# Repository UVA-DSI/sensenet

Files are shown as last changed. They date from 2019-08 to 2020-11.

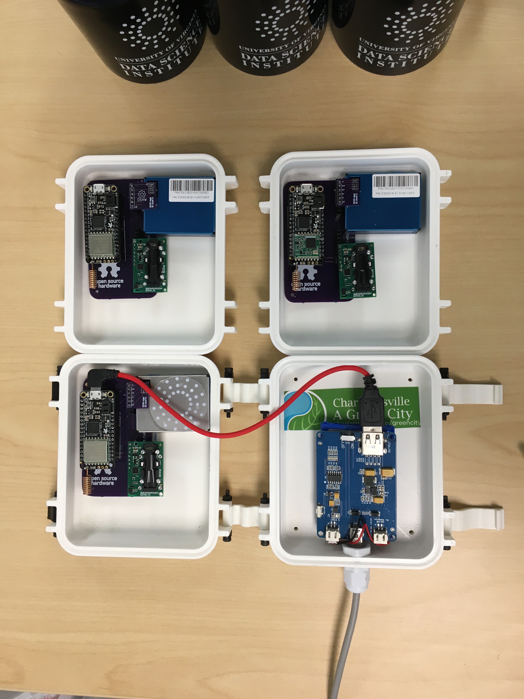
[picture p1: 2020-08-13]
projects/CCI-SDS/images/scville-hw-kit-assembled3.jpg

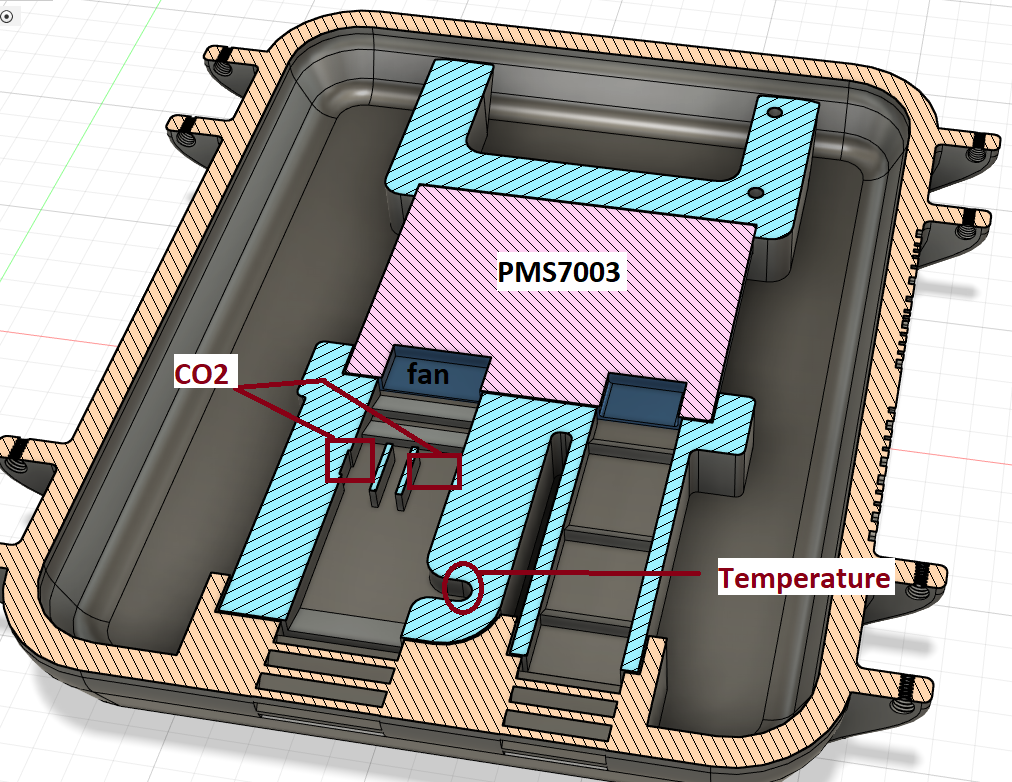
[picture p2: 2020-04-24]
projects/CCI-SDS/3D-design/box/Sensenet_Internal_cut2.png

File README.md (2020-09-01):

# Sensenet: networked environmental sensing for all

This repository contains the documentation for the 'Sensenet'
project. Here you will find the software and hardware sources 
for the backend, frontend, and sensor devices we use.

## What is included in this repository

We organized projects in folders with their resources (hardware, 
firmware, software, datasheets, and relevant documentation).

We also included 'playbooks' for the backend configuration under the
directory 'ansible' and 'conf'. They are meant to provision the 
complete backend which includes: [MQTT broker (mosquitto)](mqtt.md), 
timeseries database (influx-db), and a visualization tool (Grafana). 
For more info about the line protocol used for the timeseries db, 
[check our documentation](timeseries-db.md).

Each directory contains information about the sensors we are testing.
For more details, [check out the 'sensor-specification'](sensor-spec.md) 
document and the 'datasheets' directory.

## Implementations

We use different sensors, microcontrollers, and tools for different
implementations. You can get more information about each set-up following
the links below:

* [Networked Public Spaces, 2020-2021](projects/NPS/README.md)
* [Smartcville + School of Data Science, 2019-2020](projects/CCI-SDS/README.md)

## Contact and licensing info

Check the AUTHORS file for the list of contributors. For more 
information about each project, check the file CONTRIBUTORS.

All software is licensed as GPLv3; all hardware is licensed as
CERN-OHL-S-v2, and all documentation is released as 'CC-BY-SA-4.0
International', unless specified in the LICENSE file included in
the directory or in the header of source files.

__Happy environmental sensing and hw hacking!__

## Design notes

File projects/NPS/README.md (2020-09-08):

# Networked Public Spaces (NPS) project

"Network Public Spaces" is a collaborative project involving the School
of Data Science and the School of Architecture at UVA for the study and
implementation of community-based environmental sensor networks.

In this repository you will find the design files and source code for the
development board we are designing for low-energy LoRa applications.

## Development board 

Under the folder ["board"](board/) we keep all the design files under 
development for our dev board, sensenet: Big Dot.

## Testing 

We are using the SAML21 Xplained board for testing purposes. The information
on how to flash the bootloader we use on this board can be found at 
[SAML21-XPLAINED folder](SAML21-xplained-board/README.md).

## Installations

Ostenda Illuminata is the first installation of this project. Source code
can be found in the folder `ostenda-esp32s`.

## Dev team

Our team is composed by:

-
-
- 

Alumni:

- Keerthi Radhakrishnan

## Contact and licensing info

Please check the AUTHORS and LICENSE files for more info.

__Happy hardware hacking!__

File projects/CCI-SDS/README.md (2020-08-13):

# A LoRaWAN-Based Air Quality Sensor Network for the Public Good (2019-2020)

In this project, we evaluated, tested, and deployed a pilot wireless sensor network in collaboration 
with the Center for Civic Innovation, Smart Cville, and the UVA Linklab. This project was conducted 
by James Howerton and Ben Schenck under the mentorship of L.F.R. Murillo, Jon Kropko, Lucas Ames, and 
Jon Goodall.

Here you will find the technical document for the hardware, firware, and software we developed and used
for this project. This README is for development purposes only. 

For more information, [please visit the portfolio and access the paper "A LoRaWAN-based AQ Sensor 
Network for the Public Good" by Howerton and Schenck](https://thejimster82.github.io/CvilleAQ).

## Things Network Cville

Our project took advantage of an existing LoRa network in the city of Charlottesville. This network is 
run by Smart Cville as an open community resource. When we started, there were only 5 gateways. We expanded
the network, so it now counts with [12 gateways that can seen here](https://www.thethingsnetwork.org/community/charlottesville/).

## Data

We collected PM2.5 (ppm), PM10 (ppm), temperature (C), CO2 (ppm) and humidity (%) with 10 boxes for 
the period of five months. This data can be obtained directly from our visualization tool below, or [already 
cleaned and ready to use in this directory](https://github.com/thejimster82/CvilleAQ/tree/master/notebooks/data).

For information on how to query for data on Influxdb, please use this [notebook](https://github.com/UVA-DSI/sensenet/blob/master/projects/CCI-SDS/notebooks/influxdb-sensenet-example.ipynb). Our data is made "open" according to the ["Open Data" definition](http://opendatahandbook.org/guide/en/what-is-open-data/).

## Data Visualization

We are using two platforms to visualize the data we generated: Grafana and Luftdaten. The first
includes the unprocessed data from our ground sensors. The latter is a global network for particulate
matter sensing (PM). We use their mapping tool to visualize our data and to calculate the official
index of the US Environmental Protection Agency (EPA "Air Quality Index").

[Click here to visualize in real-time our environmental metrics (of the last 24 hours.](https://sensors.unixjazz.org/d/xUrC1m8Zz/sbox-all?from=1583213342024&to=1583299742024&orgId=1)

You can pick different time periods or select individual sensors by clicking on them, next to the graph.
Our data collection period started in February, 2020 and ended in June, 2020.

[Click here to visualize how these values map out to city locations.](https://maps.sensor.community/#13/38.0307/-78.4931)

You can select different metrics, such as (PM2.5, PM10 or check the EPA AIQ calculation) by clicking on 
the green menu at the bottom left of the map. Several zoom levels can also be selected, but the zoom
stops at #15 to avoid providing close GPS coordinates for where the environmental sensor is actually 
located.

## Hardware

We have deployed a sensor box equipped with the following hardware:

* SAMD21 microcontroller 
* LoRa RFM98 radio chip
* PMS7003 particulate matter sensor
* Sensiron SCD30 CO2 sensor
* Voltaic 1W solar panel + 4000mAh battery

The firmware can be found in the 'sensorbox' folder. The 'hardware' folder contains the connectors
and 'motherboard' PCBs we generated for this project. Here is picture of [our first prototype, v.1](images/proto_v1.jpg),
and here is another of our revised prototype [v.2](images/proto_v2.jpg). We also included more pictures  
of the hardware in the folder "images".

### How to Use the Sensor Box

The sensor boxes have been insulated with silicone coating and protected with a watertight box. It is
not, however, completely insulated as it contains holes for the sensors. Here are the elements one must
pay attention to:

* Placement: the boxes are placed at ground level (up to 10 meters), exposed to sun light, but
protected from direct rain and snow. Once it is placed in one location, write down the coordinates,
and do not move it.

* Wiring: here are the schematics on [how to wire the sensors to the microcontroller board.](images/wiring.png)

* Battery: our set-up is currently not adjusted for low-power applications, it will not last on a battery 
for more than a week if there is no sun exposure. In our experience, the 4000mAh will last for 12 days on average
without sun exposure. During the summer, however, the box does not need to be recharged if properly placed in a 
sunny spot. [Here are the instructions to put the battery on "Always On mode, which is ** necessary ** 
for its functioning in our set-up.](https://voltaicsystems.com/always-on-batteries)

## Firmware

All the code is located in the folder "sensorbox" under the name of "sbox0".

## Data Analysis

The end goal is to use the data we collected for evaluating the health impact of compounded environmental
metrics. There are three basic directions: 1) calculating averages and displaying their geolocation; 2)
creating a geospatial model for evaluating how certain concentrations might affect different parts of 
the city and certain vulnerable groups; and 3) experiment with ML-based models for outlier detection
and sensor calibration.

For more information about data analytics, check the Jupyter notebooks we prepared under the folder "notebooks".

## Commitment to Data Ethics, Privacy & Security

One of the key goals was to introduce data science students to "open data" practices (open standards, APIs,
data practices w/ Free and Open Source software and hardware) while helping them navigate data ethics issues 
to dispel the idea that public data is exempt of ethical implications.

Questions of concern for the project participants are: What are the ethical implications of 
large-scale data collection for individuals and public institutions? How should open data be gathered, 
distributed, and used? How should sensor data be collected, organized, and distributed, taking into account 
individual rights to anonymity and privacy? What qualifies as consent in our network and what are the limits
of data capture? And, finally, why we do not need an "Internet of Things" but an "Internet of People"? That is,
a network that is owned and managed by the public for the public good?

Our dataset does not include data from humans, but that does not mean it does not have ethical implications. 
Exact GPS coordinates for the location of our boxes were not made publically avaliable, only approximate sensor locations
are being published. Our commitment to openess with respect to our technologies and infrastructures does not mean
we do not value privacy rights and indiscriminate data collection. Our primary goal is to collect environmental data
whose benefit includes every breathing and living being. For our purposes, we believe it is justifiable and justified
to collect environmental data to address environmental issues and questions of environmental justice.

## Contact and Licensing Info

Check the file AUTHORS for the list of contributors to this repository. For licensing information, check the
header of a source file or the file LICENSE in the directory of a particular resource (firmware, software,
research notebook, etc.).

__Happy Environmental Monitoring and Hardware Hacking!__

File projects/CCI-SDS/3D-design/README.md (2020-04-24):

# 3D Design Files

We included here the 3D design files for the Smart Cville + School of Data Science project.
Here you will find:

* Support structures for sensors ('suport/')
* Insulated sensor box ('box/')
* Other support files

## Authors and Licensing info

3D box design was done by Luke Pi (@zx82net, Thingiverse), 2019 and Leonardo R. Murillo, 2020.
3D sensor support design was done by Leonardo R. Murillo, 2020.

All design files are distributed with CC-BY-NC-SA 4.0 International.

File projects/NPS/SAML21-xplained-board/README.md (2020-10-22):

# SAML21 Prototyping Notes

In this document, we describe the steps for setting up the SAML21 Xplained Pro dev board.

## Bootloader Installation

We must use a set of tools for writing the bootloader and firmware files to the SAML21 for prototyping purposes. Here are the steps to get it up and running:

**Dependencies**

- OpenOCD v.0.10.0 or superior
- [GCC-arm-none-eabi-7-2017-q4-major](https://developer.arm.com/tools-and-software/open-source-software/developer-tools/gnu-toolchain/gnu-rm/downloads) (this is also included in the official fork of ArduinoCore-SAMD, installable through the Arduino IDE Boards Manager)
- [BOSSA](https://github.com/shumatech/BOSSA/releases)
- Debian 10 (or any other distro) w/ extra packages: 'libwxgtk3.0-dev' and 'libreadline-dev'
- [Mattair's fork of ArduinoCore w/ SAML21 support](https://github.com/mattairtech/ArduinoCore-samd) (install instructions are towards the bottom of the README.md of that repository)

### Building the Bootloader

*Note: there are precompiled binaries included in the `bootloader` directory*

We need to build the bootloader for our board and our specific target MCU. Change to the directory `bootloader/ArduinoCore-samd-1.6.18-beta-b1/bootloaders/zero` and type:

```
$ BOARD_ID=XPLAINED_SAML21 MCU=SAML21J18B make all mostly_clean
```

After a few moments, you will have the bootloader (8K) with USB terminal support ready in the file `sam_ba_XPLAINED_SAML21_SAML21J18B.bin`.

### Runing OpenOCD

#### Using Atmel EDBG

Plug the USB cable on the 'debug USB' port and run OpenOCD w/ the configuration file included in the `openocd-conf` directory.

```
$ openocd -f openocd-SAML21.cfg
```
If everything goes as planned, you will see this output:

```
cortex_m reset_config sysresetreq
Info : CMSIS-DAP: SWD  Supported
Info : CMSIS-DAP: Interface Initialised (SWD)
Info : CMSIS-DAP: FW Version = 03.25.01B6
Info : SWCLK/TCK = 1 SWDIO/TMS = 1 TDI = 1 TDO = 1 nTRST = 0 nRESET = 1
Info : CMSIS-DAP: Interface ready
Info : clock speed 400 kHz
Info : SWD DPIDR 0x0bc11477
Info : at91saml21j18.cpu: hardware has 4 breakpoints, 2 watchpoints
```

Do not close this terminal or exit out of OpenOCD for the next steps. 

#### Using ATMEL-ICE

If you are privileged enough to have an ATMEL ICE programmer, you can use it to program the bootloader on a brand new chip. 

Please note that you can also use any STM32F103 that you might have laying around... 
In any case, here is how to do it with the super expensive programmer!

First, ensure the 'target chip' is set properly to match your chip in the `openocd-ATMEL-ICE.cfg` file.

```T
# target chip
set CHIPNAME at91saml21j18
source [find target/at91samdXX.cfg]
```

 Plug your programmer's SAM port to the "Cortex Debug" header of your board. Then, power your board via the target USB port with and run:

```
$ openocd -f openocd-ATMEL-ICE.cfg
```

This is the output you will see on your console:

```
Info : Listening on port 6666 for tcl connections
Info : Listening on port 4444 for telnet connections
Info : CMSIS-DAP: SWD  Supported
Info : CMSIS-DAP: JTAG Supported
Info : CMSIS-DAP: FW Version = 01.00.0021
Info : CMSIS-DAP: Serial# = J42700024764
Info : CMSIS-DAP: Interface Initialised (SWD)
Info : SWCLK/TCK = 1 SWDIO/TMS = 1 TDI = 1 TDO = 1 nTRST = 0 nRESET = 1
Info : CMSIS-DAP: Interface ready
Info : clock speed 400 kHz
Info : SWD DPIDR 0x0bc11477
Info : at91saml21j18.cpu: hardware has 4 breakpoints, 2 watchpoints
Info : starting gdb server for at91saml21j18.cpu on 3333
Info : Listening on port 3333 for gdb connections
```

Do not close this terminal or exit out of OpenOCD for the next steps.

### Write Bootloader

If you are dealing with a new chip, you will have to write the bootloader and set the fuses to protect it w/ OpenOCD. First connect to the chip:

```
$ telnet 0 4444 
```
Now you can write the bootloader:

```
reset halt
at91samd bootloader 0
program sam_ba_Generic_x21J_SAML21J18B.bin verify
at91samd bootloader 8192	# this command is optional, recommended to prevent BOSSA from erasing bootloader
reset
shutdown
```
The precompiled bootloader image for the SAML21J18B was obtained from the Mattair's repository. You can find more information on how to compile the bootloader image from the documentation of his fork.

If everything goes well, you are now ready to write your programs using the Arduino core framework to the target (SAML21). This is the output of a successful verification:

```
** Programming Started **
auto erase enabled
Info : SAMD MCU: SAML21J18B (256KB Flash, 32KB RAM)
wrote 16384 bytes from file /home/unixjazz/code/SAML21-xplained-board/bootloader-arduino/sam_ba_Generic_x21J_SAML21J18B.bin in 3.540651s (4.519 KiB/s)
** Programming Finished **
** Verify Started **
verified 4964 bytes in 0.181510s (26.707 KiB/s)
** Verified OK **
** Resetting Target **
```

You should verify if everything is fine by checking if the board is properly enumerated by running

```
# dmesg
```

This should return the following output:

```
usb 3-1.2: New USB device found, idVendor=0000, idProduct=0000, bcdDevice= 2.00
usb 3-1.2: New USB device strings: Mfr=1, Product=2, SerialNumber=0
cdc_acm 3-1.2:1.0: ttyACM0: USB ACM device
```

Please note that for actual usage, a board definition needs to be specified with the SAML21 Xplained board pinout. We currently do not have the board description ready for Big Dot. This is on our the TODO list.

Voilà! Toolchain and programmer are now ready for embedded fun to start.

### Flash Your Firmware

You are now ready to upload an Arduino sketch (such as `usb-term-test.bin` under the `sketches` directory) to test the USB terminal.

If you plug your board using the 'target USB' port, it should enumerate and you should have access to it. Now, you can use any tool to program your device using the USB port. You can use any sketch that makes use of USB output to test.

## Using BOSSA

Once you have the bootloader installed, you can use the `bossa` GUI utility or the `bossac` command-line utility to flash firmware onto the chip.

### Compile BOSSA

Just run `make` and `make install` to get it all ready. The binaries will be on the folder 'bin/' (`bossa`: GUI, and `bossac`: command-line tool).

### Flashing the Sample Firmware

First, test that the bootloader is successfully installed by attempting to flash the demo firmware:

```
$ bossac -e -w -v -o 8192 -b usb-term-test.bin
```

If it is successful, then you should get the following message:

```
Erase flash

Done in 0.901 seconds
Write 11856 bytes to flash (186 pages)
[==============================] 100% (186/186 pages)
Done in 0.068 seconds
Verify 11856 bytes of flash
[==============================] 100% (186/186 pages)
Verify successful
Done in 0.096 seconds
Set boot flash true
```

If you get the message

```
Device unsupported
```

and the device is properly enumerated, then press the reset button twice to enter bootloader mode.

To test to see if the sample firmware is working correctly, first open a terminal and run

```
$ screen /dev/ttyACM0
```

or use your favored serial monitor.

__Happy hw hacking!__

-- Sign-off: Teagan Le, 10/21/2020

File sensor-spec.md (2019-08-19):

# Sensor specfication

This document describes sensor names, endpoints, units,
and accuracy information. Check the 'datasheets' directory
for detailed specifications.

---
Name: BMP388
Fabricant: Bosch
Type: Temperature and pressure
```
Endpoint: 
        temp/
	press/
Units: 
        temp/		(°C celsius)
        press/ 		(hPa hectopascal)

Accuracy:  
       temp/		(±0.5 °C)
       press/   	(8 Pascals, ± 0.5 meter)
```
---
Name: SGP-30
Fabricant:
Type: 
Endpoint:
```
```

---
Sign-off: LFRM, 08-01-2019

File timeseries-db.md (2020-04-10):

# Timeseries db 'line protocol'

Influxdb is 'schemaless' which means it will generate a new series
when we send an insert statement with new 'tags' (such as sensor_type).
Once a field has been created with a particular type (float / int),
trying to write a different data type on it will generate an error.

Here is the suggested structure for data points on the database:

```
NETWORK_NAME,dev=DEV_ID,loc=DEV_LOC,topic=SENSOR_TYPE value=VALUE TIMESTAMP
```

Where:

* 'NETWORK_NAME': sensor network identifier (string)
* 'DEV_ID': device identifier (string)
* 'DEV_LOC': device localization (string)
* 'SENSOR_TYPE': temp, CO2, lux, pm25, CO2, humidity, etc. (string)
* 'VALUE': sensor measurement value (float)
* 'TIMESTAMP': timestamp of measurement (Unix epoch)

Here is an example:
```
sds-sensenet,dev=sbox1,loc=loc0,topic=temp value=32.02 1566183001355985604
```

Observations:

* There is no need to provide a TIMESTAMP (if running NTP);
* TIMESTAMP is always UTC (in Unix epoch format);
* Field keys (value) are required, they are always strings;
* Field values are 'floats' by default;
* Tags are indexed, fields are not: avoid having too many tags.

## Influxdb basic query language

For queries, we can use the API or the influxdb client:

```
influx -host example.org -port 8086 -ssl -username $USER -p YOURPASSWD
```

If self-signed certificates are being used, add '-unsafeSsl'.
You can also display timestamps in RFC-3339 format by adding '-precision rfc3339'. 
The date-time will be conveniently displayed in [Gregorian format / UTC](https://www.ietf.org/rfc/rfc3339.txt). 

## Basic command list

To list existing databases:

```
show databases
```

To select a particular database:

```
use $DATABASENAME 
```

To list existing 'measurements' (e.g. particular type of sensor):

```
show measurements
```

To query for the whole time series of a measurement:

```
select * from temp_sensor 
```

To insert a data point:

```
insert $MEASUREMENT metric_a=0.1, metric_b=1.90 
```

Field data types cannot be changed after they are entered for the
first time. To update any db entry, use the same timestamp with 
the 'insert' statement:

```
insert $MEASUREMENT metric_a=0.1, metric_b=1i ('i' stands for int) $ORIGINAL_TIMESTAMP
```

To delete data points from a particular period of time, use:

```
delete from $MEASUREMENT where time < or > or = ($TIME_IN_UNIX_EPOCH or "2020-02-01")
```

To move all the data from a 'measurement' (tables) to another DB, use:

```
select * into DB..$MEASUREMENT from DB2..$MEASUREMENT_TO_COPY_FROM group by *
```

Another convenient way of pulling data is using a IPython notebook and/or performing
a HTTP request with 'curl' to obtain a CSV file. You can request the whole time series
or select, for example, the past 2 days of data:

```
curl -H "Accept: application/csv" -G 'https://$YOURSERVER:8086/query' --insecure --data-urlencode "db=$YOUR_DB" -u "$USER:PASSWD" --data-urlencode "q=select * from \"sensenet-test\" where time >= now() - 2d" > db-dump.csv
```

For more info, check out the [query language documentation](https://docs.influxdata.com/influxdb/v1.7/query_language/database_management).

## TODO

* Improve the documentation
* Complete 'ansible' playbooks
* Test alternatives to 'Influx DB' (given its proprietary HA components)

---
Sign-off: LFRM, 02-02-2019

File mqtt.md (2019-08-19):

# Mosquitto MQTT broker

We use SSL for communicating between MCUs and servers
using MQTT, a light-weight protocol for transmitting
sensor data. 

After generating the certs for the servers with 
'Lets Encrypt', we can test the SSL communication 
with the following command:

```
mosquitto_sub -h example.org -t '#' -p 8883 --capath /etc/ssl/certs -u USER -P PASSWD
```

For posting on a topic, use the follwing command for testing purposes:

```
mosquitto_pub -h example.org -t test -m "hello world" -p 8883 --capath /etc/ssl/certs -u USER -P PASSWD
```

The following lines must be passwd to 'mosquitto.conf' 
for setting up SSL:

```
listener 8883
certfile /etc/letsencrypt/live/example.org/fullchain.pem
cafile /etc/letsencrypt/live/example.org/ca.pem
keyfile /etc/letsencrypt/live/example.org/privkey.pem
```

This is how we obtain the broker cert fingerprint to use
with the SSL client on the MCU (ESP, Yun, etc.):

```
openssl x509 -noout -in /etc/letsencrypt/live/example.org/cert.pem -fingerprint
```
 
--
Sign-off: LFRM, 06-20-2019

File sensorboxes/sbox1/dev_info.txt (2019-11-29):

DEVICE INFO
-----------
DEV_name = 
DEV_mac = 
DEV_clock = 160
DEV_ID = sbox1
LOC =

SENSOR1 = BMP-388 (temp)
SENSOR2 = BMP-388 (pressure)
SENSOR3 = HTU21D-F (humidity)
SENSOR4 = SGP30 (TVOC)
SENSOR5 = SGP30 (eCO2)
SENSOR6 = SGP30 (H2)
SENSOR7 = SGP30 (Ethanol)
SENSOR8 = VEML7700 (lux)
SENSOR9 = VEML7700 (white)
SENSOR10 = VEML7700 (ALS)

SENSOR1_TOPIC   "/sbox1/loc0/temp"
SENSOR2_TOPIC   "/sbox1/loc0/pressure"
SENSOR3_TOPIC   "/sbox1/loc0/humidity"
SENSOR4_TOPIC   "/sbox1/loc0/TVOC"
SENSOR5_TOPIC   "/sbox1/loc0/CO2"
SENSOR6_TOPIC   "/sbox1/loc0/H2"
SENSOR7_TOPIC   "/sbox1/loc0/ethanol"
SENSOR8_TOPIC   "/sbox1/loc0/lux"
SENSOR9_TOPIC   "/sbox1/loc0/white"
SENSOR10_TOPIC   "/sbox1/loc0/ALS"

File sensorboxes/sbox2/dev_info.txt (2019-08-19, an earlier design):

DEVICE INFO
-----------
DEV_name = yun
DEV_mac =
DEV_clock = 
DEV_ID = sbox2
LOC =

SENSOR1 = MQ-2 smoke sensor (mq2)
SENSOR2 = Shinyei PM2.5/10 sensor (pm)
SENSOR3 = HCHO sensor (hcho)
SENSOR4 = MQ-5 propane sensor (mq5)

SENSOR1_TOPIC   "/sbox2/loc0/mq2"
SENSOR2_TOPIC   "/sbox2/loc0/pm"
SENSOR3_TOPIC   "/sbox2/loc0/hcho"
SENSOR4_TOPIC   "/sbox2/loc0/mq5"

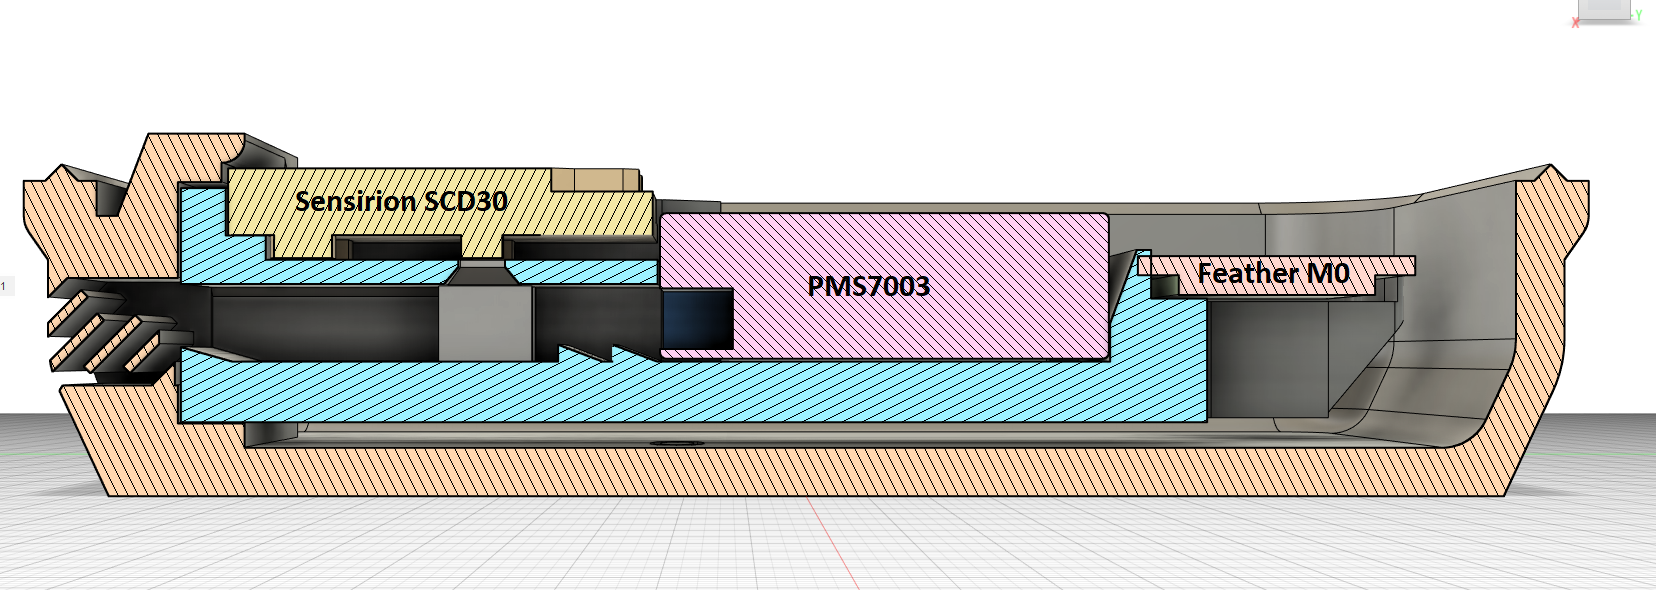
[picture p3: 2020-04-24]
projects/CCI-SDS/3D-design/box/Sensenet_Internal_cut1.png

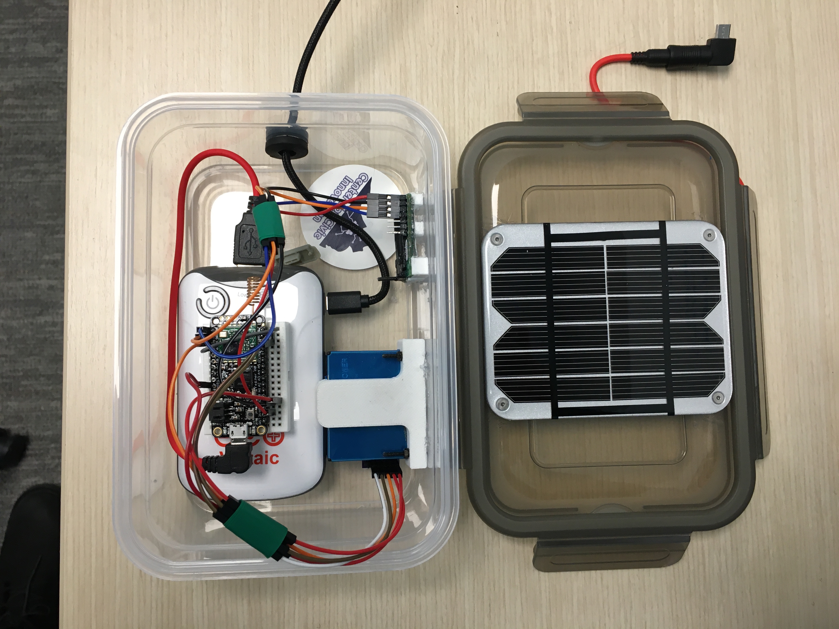
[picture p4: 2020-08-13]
projects/CCI-SDS/images/proto_v1.jpg

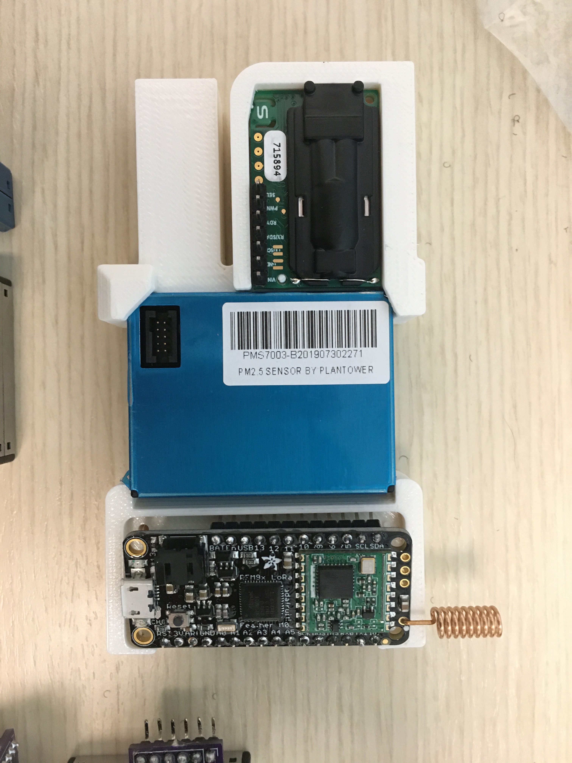
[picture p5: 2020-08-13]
projects/CCI-SDS/images/3D-model1.jpg

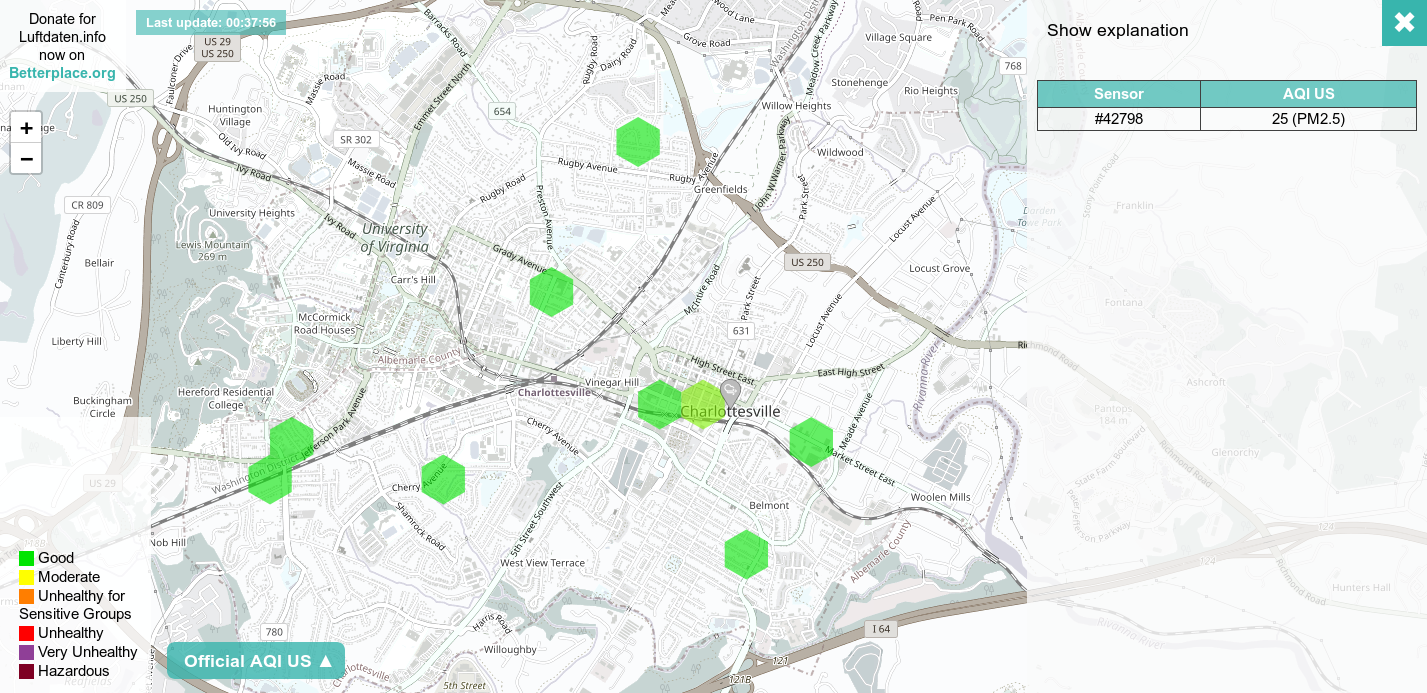
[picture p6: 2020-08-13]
projects/CCI-SDS/images/luftdaten-map-cville.png

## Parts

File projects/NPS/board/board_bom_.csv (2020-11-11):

Component | Description | Part | References | Value | Footprint | Quantity Per PCB | Datasheet | Partnumber | Mouser # | link | observations
1 | Antenna SMA connector | Antenna connector | AE1 | Antenna |  | 1 | https://www.mouser.com/datasheet/2/276/1/0732511150_RF_COAX_CONNECTORS-173168.pdf | Molex 732511150 | 538-73251-1150 | https://www.mouser.com/productdetail/molex/73251-1150?qs=wUVoC1r15A9suyHDcEhR4Q%3D%3D | expensive… find alternative
2 | Unpolarized capacitor | C | C3 C4 C5 C8 C12 C13 C15 | 100n | 1206 | 7 | ~ | 1206ZC104KAT2A | 581-1206ZC104KAT2A | https://www.mouser.com/ProductDetail/AVX/1206ZC104KAT2A?qs=%2FWgV6mHBLO3f0%2FsYQX9E1Q%3D%3D | Ceramic Capacitors MLCC - SMD/SMT 10V .1uF X7R 1206 10%
3 | Unpolarized capacitor | C | C1 C10 C14 | 10u | 1206 | 3 | ~ | 1206ZC106KAT2A | 581-1206ZC106KAT2A | https://www.mouser.com/ProductDetail/AVX/1206ZC106KAT2A?qs=1X9trZCrWl2k29mk2D2bsQ%3D%3D | Ceramic Capacitors MLCC - SMD/SMT 10V 10uF X7R 1206 10%
4 | Unpolarized capacitor | C | C11 | 1u | 1206 | 1 | ~ | 1206ZC105KAT2A | 581-1206ZC105K | https://www.mouser.com/ProductDetail/AVX/1206ZC105KAT2A?qs=%2FWgV6mHBLO2aWiMfTNPacw%3D%3D
5 | Unpolarized capacitor | C | C2 | 2.2u | 1206 | 1 | ~ | 1206ZC225KAT2A | 581-1206ZC225K | https://www.mouser.com/ProductDetail/AVX/1206ZC225KAT2A?qs=XLT4Ltk6ueE4RQ7L0aAPFQ%3D%3D
6 | Unpolarized capacitor | C | C7 | 4.7u | 1206 | 1 | ~ | 1206ZC475KAT2A | 581-1206ZC475KAT2A | https://www.mouser.com/ProductDetail/AVX/1206ZC475KAT2A?qs=a08fxVRGePm0oM7133%252BqYw%3D%3D
7 | Unpolarized capacitor | C | C6 C9 | 22pF | 1206 | 2 | ~ | 1206N220J100CT | 791-1206N220J100CT | https://www.mouser.com/ProductDetail/Walsin/1206N220J100CT
8 | Light emitting diode | LED | D2 | LED | 1206 | 1 | https://www.mouser.com/datasheet/2/216/APT3216LZGCK-535785.pdf | APT3216LZGCK | 604-APT3216LZGCK | https://www.mouser.com/ProductDetail/Kingbright/APT3216LZGCK | revise LED specs for final board (!)
9 | Schottky diode | D_Schottky | D1 | MBR120 |  | 1 | https://www.mouser.com/datasheet/2/308/MBR120VLSFT1-D-1810842.pdf | MBR120VLSFT3G | 863-MBR120VLSFT3G | https://www.mouser.com/ProductDetail/ON-Semiconductor/MBR120VLSFT3G | revise footprint
10 | Ferrite bead | Ferrite_Bead | FB1 | FBMH3216HM221NT | 1206 | 1 | https://www.mouser.com/datasheet/2/396/TaiyoYuden_chipbeads01_e-1274227.pdf | FBMH3216HM221NT | 963-FBMH3216HM221NT | https://www.mouser.com/ProductDetail/Taiyo-Yuden/FBMH3216HM221NT?qs=qEEMd6hQM8XdbVk1TxAONg%3D%3D
11 | Generic connector, single row, 01x02, script generated (kicad-library-utils/schlib/autogen/connector/) | Conn_01x02 | J3 | Conn_01x02 |  | 1 | ~
12 | Generic connector, single row, 01x03, script generated (kicad-library-utils/schlib/autogen/connector/) | Conn_01x03 | J4 | Conn_01x03 |  | 1 | ~
13 | Generic connector, single row, 01x06, script generated (kicad-library-utils/schlib/autogen/connector/) | Conn_01x06 | J5 | Conn_01x06 |  | 1 | ~
14 | Generic connector, single row, 01x13, script generated (kicad-library-utils/schlib/autogen/connector/) | Conn_01x13 | J6 | Conn_01x13 |  | 1 | ~
15 | Cortex Debug Connector, standard ARM Cortex-M SWD and JTAG interface | Conn_ARM_JTAG_SWD_10 | J1 | Conn_ARM_JTAG_SWD_10 |  | 1
16 | USB Micro Type B connector | USB_B_Micro | J2 | USB_B_Micro |  | 1 | https://www.mouser.com/datasheet/2/670/uj2_mibh2_4_smt-1313423.pdf | UJ2-MIBH2-4-SMT-TR | 490-UJ2-MIBH2-4-SMT | https://www.mouser.com/ProductDetail/CUI-Devices/UJ2-MIBH2-4-SMT-TR?qs=5mqXD9RfOg1yxHIpPvPxvQ%3D%3D | revise footprint (PCB mounting through-hole measurement)
19 | Inductor | L | L1 | 10uH |  | 1 | https://www.mouser.com/datasheet/2/445/7447918-1723051.pdf | 7447918 | 710-7447918 | https://www.mouser.com/ProductDetail/Wurth-Elektronik/7447918?qs=T3oQrply3y%2FV2tNxb67AfA%3D%3D | Needed for switching + linear functioning of SAML21 | rated at 25 mA (max)
20 | P-MOSFET transistor, gate/drain/source | Q_PMOS_GDS | Q1 Q2 | Si2365EDS | Sot-23 | 2 | https://www.mouser.com/datasheet/2/427/si2365eds-1764304.pdf | SI2365EDS-T1-GE3 | 78-SI2365EDS-T1-GE3 | https://www.mouser.com/ProductDetail/Vishay-Semiconductors/SI2365EDS-T1-GE3?qs=KLh5H0KA3CPh9IaAAntwZA%3D%3D | part number is wrong in the schematic | part alias: SI4816DY-T1-E3-S
21 | Resistor | R | R3 R6 | 10k | 1206 | 2 | ~ | CR1206AFX-1002EAS | 652-CR1206AFX1002EAS | https://www.mouser.com/ProductDetail/Bourns/CR1206AFX-1002EAS
22 | Resistor | R | R1 | 1k | 1206 | 1 | ~ | CRG1206F1K0/10 | 279-CRG1206F1K0/10 | https://www.mouser.com/ProductDetail/TE-Connectivity-Neohm/CRG1206F1K0-10
23 | Resistor | R | R5 | 2.2k | 1206 | 1 | ~ | CRCW12062K20FKEAC | 71-CRCW12062K20FKEAC | https://www.mouser.com/ProductDetail/Vishay-Dale/CRCW12062K20FKEAC
24 | Resistor | R | R2 R7 | 330 | 1206 | 2 | ~ | RC1206FR-10330RL | 603-RC1206FR-10330RL | https://www.mouser.com/ProductDetail/Yageo/RC1206FR-10330RL
25 | Resistor | R | R4 | 4.7 | 1206 | 1 | ~ | RC1206FR-134K7L | 603-RC1206FR-134K7L | https://www.mouser.com/ProductDetail/Yageo/RC1206FR-134K7L?qs=rU22MploB9rODHAzWCDVgA%3D%3D
26 | Push button switch, generic, two pins | SW_Push | SW1 | SW_Push |  | 1 | https://www.mouser.com/datasheet/2/358/typ_6x6_mm_tact_switches-1275689.pdf | 1301.9314 | 693-1301.9314 | https://www.mouser.com/ProductDetail/Schurter/13019314?qs=tGaZrb6HVSbFYC4o6ZpHBA%3D%3D
27 | Temperature dependent resistor, negative temperature coefficient | Thermistor_NTC | TH1 | NTHS1206N02N1002JE | 1206 | 1 | https://www.vishay.com/docs/33008/nths.pdf | NTHS1206N02N1002JE | 71-NTHS1206N2N1002JE | https://www.mouser.com/productdetail/vishay-dale/nths0603n02n1002je?qs=LgTaXJieli1ZZmTOvBaZxA%3D%3D
28 | SAM L21 Microchip SMART ARM-based Flash MCU, 48Mhz, 256K Flash, 32K SRAM, TQFP32 | ATSAML21E18B-AUT | U4 | ATSAML21E18B-AUT | TQFP-32_7x7mm_P0.8mm | 1 | http://ww1.microchip.com/downloads/en/DeviceDoc/SAM_L21_Family_DataSheet_DS60001477C.pdf | ATSAML21E18B-AUT | 556-ATSAML21E18B-AUT | https://www.mouser.com/ProductDetail/Microchip-Technology-Atmel/ATSAML21E18B-AUT | Expensive… 4 dollars a piece
29 | Battery Management Simple Low-IQ Battery Charger/Protector with NTC Thermistor Input | LTC4070 | U2 | LTC4070 | MSOP-8 | 1 | https://www.mouser.com/datasheet/2/609/LTC4070-1776059.pdf | LTC4070EMS8E#PBF | 584-LTC4070EMS8E#PBF | https://www.mouser.com/ProductDetail/Analog-Devices/LTC4070EMS8EPBF?qs=hVkxg5c3xu9ctYAwRJVxEA%3D%3D | Find alternative… package too small
30 |  | MCP1812 | U1 | MCP1812A | SOT-23-3 | 1 | https://www.mouser.com/datasheet/2/268/MCP1811A-11B-12A-12B-Family-Data-Sheet-DS20006088A-1488740.pdf | MCP1812AT-033/TT | 579-MCP1812AT-033/TT | https://www.mouser.com/ProductDetail/Microchip-Technology/MCP1812AT-033-TT?qs=byeeYqUIh0OYc3EsjlWrlQ%3D%3D
31 | Low power long range transceiver module, SPI and parallel interface, 915 MHz | RFM95W-915S2 | U3 | RFM95W-915S2 | custom | 1 | https://www.hoperf.com/data/upload/portal/20181127/5bfcbea20e9ef.pdf | RFM95W-915S2 | n/a | must be purchased on Taobao
32 | XTAL32 | Crystal_GND2 | Y1 | MS1V-T1K | PTH | 1 | https://www.mouser.com/datasheet/2/3/ABL-1774766.pdf | ABL-32.000MHZ-B2 | 815-ABL-32-B2 | https://www.mouser.com/ProductDetail/ABRACON/ABL-32000MHZ-B2?qs=zLkLEWnxMJxB%252Bk6YRBW6NQ%3D%3D
Component Groups: | 32
Component Count: | 44
Fitted Components: | 44
Number of PCBs: | 1
Total components: | 44
Schematic Version:
Schematic Date:
PCB Variant: | default
BoM Date: | 09/29/2020 9:31:59 PM
Schematic Source: | board.sch
KiCad Version: | Eeschema (5.1.2)-2

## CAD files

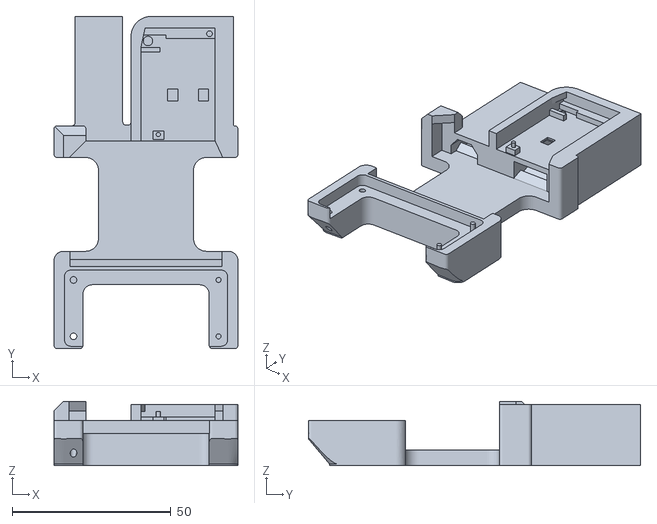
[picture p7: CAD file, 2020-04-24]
projects/CCI-SDS/3D-design/box/Sensenet_Internal_@B.stl
58.0 x 104.7 x 20.3

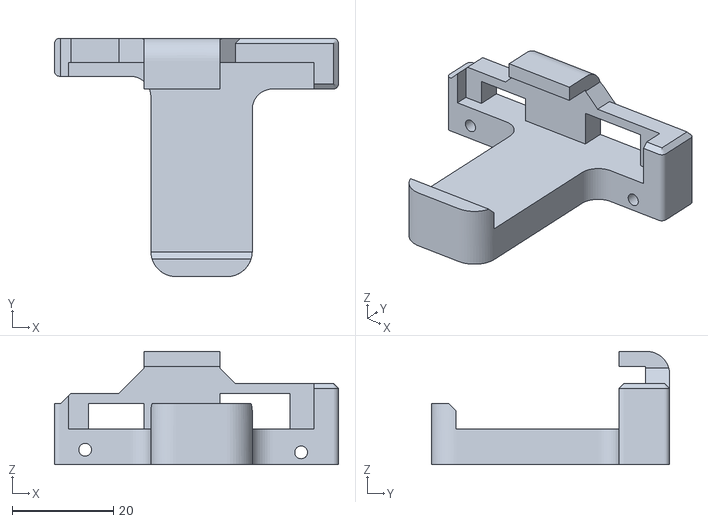
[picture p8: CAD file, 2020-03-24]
projects/CCI-SDS/3D-design/support/Support_PMS7003.stl
56.0 x 47.0 x 22.3

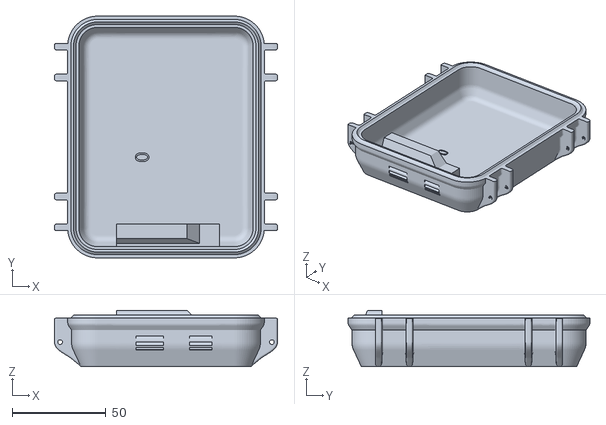
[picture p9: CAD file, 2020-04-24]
projects/CCI-SDS/3D-design/box/Sensenet_Side_@B.stl
119.0 x 129.0 x 29.9

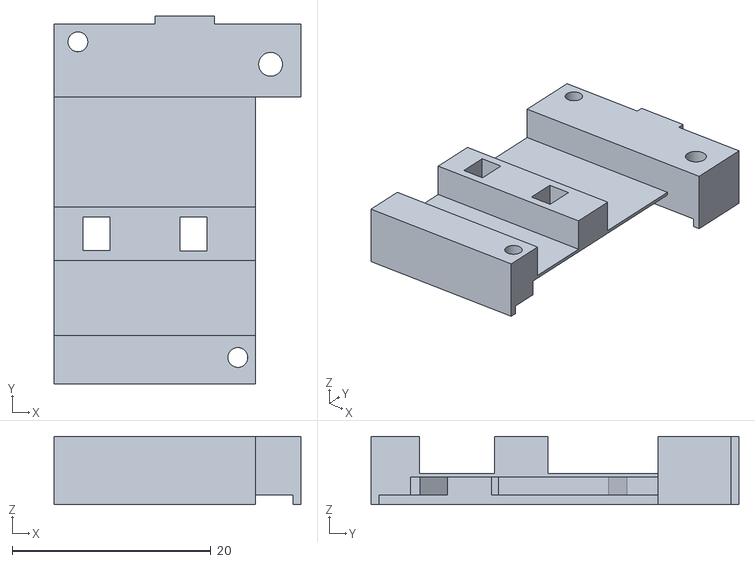
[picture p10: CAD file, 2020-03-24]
projects/CCI-SDS/3D-design/support/Support_Sensirion_SCD30.stl
24.8 x 37.0 x 6.88

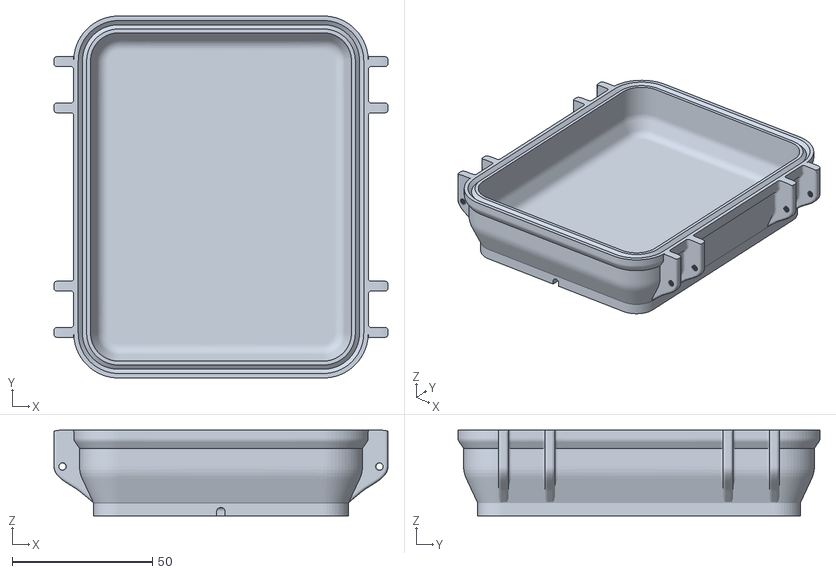
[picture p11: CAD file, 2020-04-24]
projects/CCI-SDS/3D-design/box/Sensenet_Side_A.stl
119.0 x 129.0 x 30.6

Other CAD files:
projects/CCI-SDS/3D-design/box/Sensenet_Side_@B_text.stl
projects/CCI-SDS/3D-design/box/Sensenet_Side_B.stl
projects/CCI-SDS/3D-design/box/Sensenet_Side_B_text.stl

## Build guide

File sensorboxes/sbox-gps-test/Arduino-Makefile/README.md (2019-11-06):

# A Makefile for Arduino Sketches 

This is a very simple Makefile which knows how to build Arduino sketches. It defines entire workflows for compiling code, flashing it to Arduino and even communicating through Serial monitor. You don't need to change anything in the Arduino sketches.

## Features

- Very robust
- Highly customizable
- Supports all official AVR-based Arduino boards
- Supports official ARM-based Arduino boards using Atmel SAM chip family
and includes on-device debugging targets.
- Supports chipKIT
- Supports Teensy 3.x (via Teensyduino)
- Supports Robotis OpenCR 1.0
- Works on all three major OS (Mac, Linux, Windows)
- Auto detects serial baud rate and libraries used
- Support for `*.ino` and `*.pde` sketches as well as raw `*.c` and `*.cpp`
- Support for Arduino Software versions 0.x, 1.0.x, 1.5.x and 1.6.x except 1.6.2.
We recommend 1.6.3 or above version of Arduino IDE.
- Automatic dependency tracking. Referred libraries are automatically included
in the build process. Changes in `*.h` files lead to recompilation of sources which include them

## Installation

### Through package

#### Using apt-get (or aptitude)

If you're using FreeBSD, Debian, Raspbian or Ubuntu, you can find this in the `arduino-mk`
package which can be installed using `apt-get` or `aptitude`.

```sh
sudo apt-get install arduino-mk
```

#### homebrew (or linuxbrew)

If you're using homebrew (or [linuxbrew](https://github.com/Homebrew/linuxbrew)) then you can find this in the
`arduino-mk` package which can be installed using the following commands.

Also make sure you have the necessary dependencies installed. Refer to the [Requirements](#requirements) section below to install the dependencies.

```sh
# add tap
$ brew tap sudar/arduino-mk

# to install the last stable release
$ brew install arduino-mk

# to install the development version
$ brew install --HEAD arduino-mk
```

#### Arch Linux

Arch Linux users can use the unofficial AUR package [arduino-mk](https://aur.archlinux.org/packages/arduino-mk/).
It can be installed with [AUR] helper using the following command.

```sh
yay -S arduino-mk
```

#### Fedora

Fedora Linux users can use our packaging instructions [here](https://github.com/sudar/Arduino-Makefile/tree/master/packaging/fedora)
to build an RPM.

### From source

- Download the latest release
- Or clone it from Github using the command `git clone git@github.com:sudar/Arduino-Makefile.git`
- Check the [usage section](https://github.com/sudar/Arduino-Makefile#usage) in this readme about setting usage options

## Requirements

### Arduino IDE

You need to have the Arduino IDE. You can either install it through the
installer or download the distribution zip file and extract it.

### pySerial

The Makefile also delegates resetting the board to a short Python program.
You'll need to install [`pySerial`](https://pypi.python.org/pypi/pyserial) to use it though.

On most systems you should be able to install it using either `pip` or `easy_install`.

```sh
pip install pyserial

# or if you prefer easy_install

easy_install -U pyserial
```

If you prefer to install it as a package, then you can do that as well.

On Debian or Ubuntu:

```sh
apt-get install python-serial
```

On Fedora:

```sh
yum install pyserial

# or on Fedora 22+

dnf install pyserial
```

On openSUSE:

```sh
zypper install python-serial
```

On Arch:

```sh
sudo pacman -S python-pyserial
```

On Mac using MacPorts:

```sh
sudo port install py27-serial
```

On Windows:

You need to install Cygwin and its packages for Make, Perl, Python2 and the following Serial library.

Assuming you included Python in your Cygwin installation:

1. download PySerial source package from [https://pypi.python.org/pypi/pyserial](https://pypi.python.org/pypi/pyserial)
2. extract downloaded package running `tar xvzf dowloaded_package_name.tar.gz`
3. navigate to extracted package folder
4. build and install Python module: 
 
```
python setup.py build
python setup.py install
```

Alternatively, if you have setup Cygwin to use a Windows Python installation,
simply install using pip:

```
pip install pyserial
```

Arduino-Makefile should automatically detect the Python installation type and
use the correct device port binding.

## Usage

Download a copy of this repo somewhere to your system or install it through a package by following the above installation instruction.

Sample makefiles are provided in the `examples/` directory.  E.g. [Makefile-example](examples/MakefileExample/Makefile-example.mk) demonstrates some of the more advanced options,
whilst [Blink](examples/Blink/Makefile) demonstrates the minimal settings required for various boards like the Uno, Nano, Mega, Teensy, ATtiny etc.

### Mac

On the Mac with IDE 1.0 you might want to set:

```make
    ARDUINO_DIR   = /Applications/Arduino.app/Contents/Resources/Java
    ARDMK_DIR     = /usr/local
    AVR_TOOLS_DIR = /usr
    MONITOR_PORT  = /dev/ttyACM0
    BOARD_TAG     = mega2560
```

On the Mac with IDE 1.5+ it's like above but with

```make
    ARDUINO_DIR   = /Applications/Arduino.app/Contents/Java
```
### Linux

You can either declare following variables in your project's makefile or set them as environmental variables.

```make
    ARDUINO_DIR – Directory where Arduino is installed
    ARDMK_DIR – Directory where you have copied the makefile
    AVR_TOOLS_DIR – Directory where avr tools are installed
```

Keep in mind, that Arduino 1.5.x+ comes with it's own copy of avr tools which you can leverage in your build process here.

Example of  ~/.bashrc file:

```make
    export ARDUINO_DIR=/home/sudar/apps/arduino-1.0.5
    export ARDMK_DIR=/home/sudar/Dropbox/code/Arduino-Makefile
    export AVR_TOOLS_DIR=/usr/include
```

Example of the project's make file:

```make
    BOARD_TAG     = mega2560
    MONITOR_PORT  = /dev/ttyACM0
```

### Windows

On Windows (using Cygwin), you might want to set:

```make
    # Symbolic link to Arduino installation directory - see below
    ARDUINO_DIR   = C:/Arduino
    ARDMK_DIR     = path/to/mkfile
    MONITOR_PORT  = com3
    BOARD_TAG     = mega2560
```

**NOTE: Use forward slash not backslash and there should be no spaces or
special characters in the Windows paths (due to Win/Unix crossover). The paths
should not be *cygdrive* paths.**

On Windows (using MSYS and PuTTY), you might want to set the following extra parameters:

```make
    MONITOR_CMD   = putty
    MONITOR_PARAMS = 8,1,n,N
```

On Arduino 1.5+ installs, you should set the architecture to either `avr` or `sam` and if using a submenu CPU type, then also set that:

```make
    ARCHITECTURE  = avr
    BOARD_TAG     = atmegang
    BOARD_SUB     = atmega168
```

#### Symbolic Link

It is recommended in Windows that you create a symbolic link to avoid problems with file naming conventions on Windows; unless one installs to a non-default location. For example, if your your Arduino directory is in:

    C:\Program Files (x86)\Arduino

You will get problems with the special characters on the directory name. More details about this can be found in [issue #94](https://github.com/sudar/Arduino-Makefile/issues/94)

To create a symbolic link, you can use the command “mklink” on Windows, e.g.

```sh
mklink /d C:\Arduino C:\Program Files (x86)\Arduino
```
Alternatively if you've setup Cygwin hard symbolic links ([CYGWIN=winsymlinks:native](https://www.cygwin.com/cygwin-ug-net/using-cygwinenv.html)):

```sh
ln -s /cygdrive/c/Program Files\ \(x86\)/Arduino/ C:/Arduino
```

After which, the variables should be:

```make
    ARDUINO_DIR=C:/Arduino
```

Instead of:

```make
    ARDUINO_DIR=C:/Program\ Files\ \(x86\)/Arduino
```

### Useful Variables

The list of all variables that can be overridden is available at [arduino-mk-vars.md](arduino-mk-vars.md) file.

- `BOARD_TAG` - Type of board, for a list see boards.txt or `make show_boards`
- `MONITOR_PORT` - The port where your Arduino is plugged in, usually `/dev/ttyACM0` or `/dev/ttyUSB0` in Linux or Mac OS X and `com3`, `com4`, etc. in Windows.
- `ARDUINO_DIR` - Path to Arduino installation. Using Windows with Cygwin,
  this path must use Unix / and not Windows \\ (eg "C:/Arduino" not
  "C:\\Arduino).
- `ARDMK_DIR`   - Path where the `*.mk` are present. If you installed the package, then it is usually `/usr/share/arduino`. On Windows, this should be a path without spaces and no special characters, it can be a *cygdrive* path if necessary and must use / not \\.
- `AVR_TOOLS_DIR` - Path where the avr tools chain binaries are present. If you are going to use the binaries that came with Arduino installation, then you don't have to set it. Otherwise set it relative and not absolute.

## Including Libraries

You can specify space separated list of libraries that are needed for your sketch in the variable `ARDUINO_LIBS`.

```make
	ARDUINO_LIBS = Wire SoftwareSerial
```

The libraries will be searched for in the following places in the following order.

- `/libraries` directory inside your sketchbook directory. Sketchbook directory will be auto detected from your Arduino preference file. You can also manually set it through `ARDUINO_SKETCHBOOK`.
- `/libraries` directory inside your Arduino directory, which is read from `ARDUINO_DIR`.

The libraries inside user directories will take precedence over libraries present in Arduino core directory.

The makefile can autodetect the libraries that are included from your sketch and can include them automatically. But it can't detect libraries that are included from other libraries. (see [issue #93](https://github.com/sudar/Arduino-Makefile/issues/93))

## avrdude

To upload compiled files, `avrdude` is used. This Makefile tries to find `avrdude` and it's config (`avrdude.conf`) below `ARDUINO_DIR`. If you like to use the one installed on your system instead of the one which came with Arduino, you can try to set the variables `AVRDUDE` and `AVRDUDE_CONF`. On a typical Linux system these could be set to

```make
      AVRDUDE      = /usr/bin/avrdude
      AVRDUDE_CONF = /etc/avrdude.conf
```

## Teensy 3.x

For Teensy 3.x support you must first install [Teensyduino](http://www.pjrc.com/teensy/teensyduino.html).

See examples/BlinkTeensy for example usage.

## Robotis OpenCM

For Robotis OpenCM support you must first install [the OpenCM IDE](http://support.robotis.com/en/software/robotis_opencm/robotis_opencm.htm)

See examples/BlinkOpenCM for example usage.

For large Robotis projects, [libmaple](https://github.com/Rhoban/Maple) may be more appropriate, as the OpenCM IDE uses a very old compiler release.

## Arduino ARM Boards

For Arduino boards using ARM architechure, specifically the Atmel SAM series
((SAM3X8E) Due; (SAMD21) Arduino M0 [Pro], Zero, MKR1000, Feather M0, etc.), first
install the board support package from the IDE or other distribution channels.

Define`ARDUINO_PACKAGE_DIR` as the root path containing the ARM support
package (the manufacturer folder) and the `BOARD_TAG` (see `make show_boards`
for help) within your project Makefile. Include 'Sam.mk' rather than
  'Arduino.mk' at the end of your file - see examples/ZeroBlink,
  examples/MZeroBlink and examples/DueBlink for example usage.

**Note**: The Arduino IDE does not install board support packages to
the base Arduino installation directory (the directory that will work with AVR
Makefiles). They are generally installed to a '.arduino15/packages' folder in
the users home directory. This is the reason for the new `ARDUINO_PACKAGE_DIR`
define. On Windows, the package directory is often in the user home directory
so advice is to create a symblic link to avoid slash/space in path problems.
You can also manually install support packages in your Sketchbook 'hardware'
folder, then define ARDUINO_PACKAGE_DIR as this path.

If using a SAM board from a manufacturer other than Arduino, one must still
install the Arduino board support as above (unless using externally defined
toolchain) and then define the location of the manufacturer board support core
using the ALTERNATIVE_CORE_PATH define. For example: `ALTERNATE_CORE_PATH =
$(ARDUINO_SKETCHBOOK)/hardware/sparkfun/samd`

The programing method will auto-detect based on the `BOARD_TAG` settings read
from boards.txt:

Programming using OpenOCD CMSIS-DAP with the Programming/debug USB is
currently supported (the same method used by the IDE), including burning
bootloaders. External CMSIS tools such as Atmel Ice will also work with this
method. Black Magic Probe (BMP) support is also included using GDB for both
uploading and debugging.

Native USB programing using Bossa (Due, Zero, MKR1000, Feather style bootloaders)
and avrdude (M0 bootloaders) is supported. The bootloaders on these devices
requires a double press of the reset button or open/closing the serial port at
1200 BAUD. The automatic entry of the bootloader is attempted using
`ard-reset-arduino` when using the general `make upload` target by polling
attached devices until the bootloader port re-attaches (same method as the
IDE). On Windows, the USB enumerates as differnt COM ports for the CDC Serial
and bootloader and these must be defined. On encountering problems, one can
manually enter the bootloader then upload using the `make raw_upload` target.
Note that the `make reset` target will enter the bootloader on these devices;
there is no way to reset over USB.

If using system installed tools, be aware that `openocd` and `bossa` were
orginally forked for Arduino support and system distributions may not be up
to date with merged changes. `bossa` must be version 1.7->. `openocd` should
work but there may be problems at run time
[ref](https://github.com/pda/arduino-zero-without-ide). Ideally, use the
support packaged version or compile and install the Arduino fork.

With the ARM chipset and using a CMSIS-DAP tool, on-device debugging is made available:

* `debug_init` and `debug` targets for on-device debugging using GDB. To use
  this, one must start the GDB server with `make debug_init &`, followed by
  connecting to the target with `make debug`. If using a Black Magic Probe,
  one can just use `make debug`. At the moment, a system wide `arm-none-eabi-gdb` must be
  installed as the one supplied with the Arduino toolchain
  does not appear to work. 
* Example usage: https://asciinema.org/a/Jarz7Pr3gD6mqaZvCACQBzqix
* See the examples/MZeroBlink Makefile for a commented example.

## Versioning

The current version of the makefile is `1.6.0`. You can find the full history in the [HISTORY.md](HISTORY.md) file

This project adheres to Semantic [Versioning 2.0](http://semver.org/).

## License

This makefile and the related documentation and examples are free software; you can redistribute it and/or modify it
under the terms of the GNU Lesser General Public License as
published by the Free Software Foundation; either version 2.1 of the License, or (at your option) any later version.

## Contribution

All contributions (even documentation) are welcome :) Open a pull request and I would be happy to merge them.
Also checkout the [contribution guide](CONTRIBUTING.md) for more details.

If you are looking for ideas to work on, then check out the following TODO items or the [issue tracker](https://github.com/sudar/Arduino-Makefile/issues/).

## Limitations / Known Issues / TODO's

- Since it doesn't do any pre processing like Arduino IDE, you have to declare all methods before you use them ([issue #59](https://github.com/sudar/Arduino-Makefile/issues/59))
- More than one .ino or .pde file is not supported yet ([issue #49](https://github.com/sudar/Arduino-Makefile/issues/49))
- When you compile for the first time, it builds all libs inside Arduino directory even if it is not needed. But while linking only the relevant files are linked. ([issue #29](https://github.com/sudar/Arduino-Makefile/issues/29)). Even Arduino IDE does the same thing though.
- This makefile doesn't support boards or IDE from Arduino.org.

If you find an issue or have an idea for a feature then log them in the [issue tracker](https://github.com/sudar/Arduino-Makefile/issues/)

## Interfacing with other projects/frameworks/IDE's

### Colorgcc

It is possible to use [`colorgcc`](https://github.com/colorgcc/colorgcc) with this makefile. Check out [this comment](http://hardwarefun.com/tutorials/compiling-arduino-sketches-using-makefile#comment-1408) to find usage instructions.

### Emacs/Flymake support

On-the-fly syntax checking in Emacs using the [Flymake](http://www.emacswiki.org/emacs/FlyMake) minor mode is now possible.

First, the flymake mode must be configured to recognize ino files :

Edit the flymake configuration :

```
    M-x customize-option RET
    flymake-allowed-file-name-masks RET
```

Add the line :

```
      ("\\.ino\\'" flymake-simple-make-init)
```

Then click on "Apply and Save" button

Then, the following line must be added to the project Makefile :

```make
    check-syntax:
        $(CXX) -c -include Arduino.h   -x c++ $(CXXFLAGS)   $(CPPFLAGS)  -fsyntax-only $(CHK_SOURCES)
```

### Code:Blocks integration

In Code:Blocks open Project -> Properties -> Project settings tab -> check "This is custom Makefile".

Now go to Settings -> Environment -> Environment variables -> Add

Add three keys with paths as values, using full paths (!):

```make
	ARDUINO_DIR=/full/path/to/arduino-1.0.6
	ARDMK_DIR=/full/path/to/sketchbook
	AVR_TOOLS_DIR=/usr
```

Now to set DEBUG target (this will compile the project) go to Build options -> Debug -> "Make" commands

In Build Project/Target remove $target:

```sh
$make -f $makefile
```

In Clean Project/Target remove $target:

```sh
$make -f $makefile clean
```

To set the RELEASE target (which will compile and upload) go to Build options -> Release -> "Make" commands

In Build Project/Target put:

```sh
$make -f $makefile upload
```

In Clean Project/Target remove $target:

```sh
$make -f $makefile clean
```

## Test Suite

This project includes a suite of example Makefiles and small Arduino and chipKIT
programs to assist the maintainers of the Makefile. Run
`tests/script/bootstrap.sh` to attempt to automatically install the dependencies
(Arduino IDE, MPIDE, etc.). Run `tests/script/runtests.sh` to attempt to compile
all of the examples. The bootstrap script is primarily intended for use by a
continuous integration server, specifically Travis CI. It is not intended for
normal users.

## Makefile Generator and Project Initialisation

`ardmk-init` within the bin/ folder is a utility Python script to create a
Arduino-mk Makefile for a project and also has option to create a traditional *tree*
organization (src, lib, bin). It can be used as with commanline arguments or
prompted - see examples below (append `$ARDMK_DIR/bin/` to command if not on path):

* Run prompted within current working directory: `ardmk-init`
* Create Arduino Uno Makefile (useful within a library example): `ardmk-init -qb uno`
* Create boilerplate Arduino Uno project in current working directory of same
  name: `ardmk-init -b uno --quiet --project`
* Create Arduino-mk nano Makefile in current working directory with template .ino: `ardmk-init -b nano -u atmega328 -qtn my-project`
* See `ardmk-init --help` for more.

### Bare-Arduino–Project

If you are planning on using this makefile in a larger/professional project, you might want to take a look at the [Bare-Arduino–Project](https://github.com/WeAreLeka/Bare-Arduino-Project) framework.

Similar to HTML frameworks, [Bare-Arduino–Project](https://github.com/WeAreLeka/Bare-Arduino-Project) aims at providing a basic `tree` organization, `Makefile` configurations for both OS X and Linux and a handful of instruction on how to get started with a robust Arduino project architecture.

Further information are available in the [README.md](https://github.com/WeAreLeka/Bare-Arduino-Project/blob/master/README.md) as well as in the [use/installation procedure](https://github.com/WeAreLeka/Bare-Arduino-Project/blob/master/INSTALL.md).

Please be sure to report issues to [Bare-Arduino–Project](https://github.com/WeAreLeka/Bare-Arduino-Project/issues) if you use it instead of this project.

## Credits

This makefile was originally created by [Martin Oldfield](http://mjo.tc/atelier/2009/02/arduino-cli.html) and he maintained it till v0.10.2.
From May 2013, it is maintained by [Sudar Muthu](http://hardwarefun.com/tutorials/compiling-arduino-sketches-using-makefile) and [Simon John](https://github.com/sej7278) with the help of [40+ contributors](https://github.com/sudar/Arduino-Makefile/graphs/contributors).

## Similar works
- It's not a derivative of this, but Alan Burlison has written a [similar thing](http://bleaklow.com/2010/06/04/a_makefile_for_arduino_sketches.html).
- Alan's Makefile was used in a [Pragmatic Programmer's article](http://pragprog.com/magazines/2011-04/advanced-arduino-hacking).
- Rei Vilo wrote to tell me that he's using the Makefile ina Xcode 4 template called [embedXcode](http://embedxcode.weebly.com/). Apparently it supports many platforms and boards, including AVR-based Arduino, AVR-based Wiring, PIC32-based chipKIT, MSP430-based LaunchPad and ARM3-based Maple.

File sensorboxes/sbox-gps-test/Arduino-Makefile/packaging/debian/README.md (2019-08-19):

# How to compile a Deb package

Use these instructions to build your own Deb package from your local sources.
For the latest official packages go to [Debian](http://packages.debian.org/arduino-mk)
or [Ubuntu](https://launchpad.net/ubuntu/+source/arduino-mk) or use apt.

First install the dependencies as root:

    apt-get build-dep arduino-mk
    apt-get install arduino-core build-essential dpkg-dev fakeroot devscripts

Fetch the Debian source:

    apt-get source arduino-mk

Make any local changes to want within the arduino-mk-* directory and update the package version:

    cd arduino-mk-*
    dch -i

Then compile. This will create a binary Deb:

    dpkg-buildpackage -b

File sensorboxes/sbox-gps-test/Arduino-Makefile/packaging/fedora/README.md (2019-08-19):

# How to compile an RPM

First install the dependencies as root:

```sh
    yum install arduino-core rpm-build

    # or on Fedora 22+

    dnf install arduino-core rpmdevtools
```

From the top-level Arduino-Makefile directory you've checked out of github, run the following (as unprivileged user) to create a compressed tarball using the naming conventions required by rpmbuild:

    git archive HEAD --prefix=arduino-mk-1.5/ -o ../arduino-mk-1.5.tar.gz

If you don't already have a rpmbuild setup (e.g. you've not installed the SRPM) you will need to create the directories:

    mkdir -p ~/rpmbuild/{SOURCES,SPECS}

Then copy the tarball and specfile into those directories:

    cp ../arduino-mk-1.5.tar.gz ~/rpmbuild/SOURCES/
    cp packaging/fedora/arduino-mk.spec ~/rpmbuild/SPECS/

Then compile. This will create a binary and source RPM:

    cd ~/rpmbuild/SPECS/
    rpmbuild -ba arduino-mk.spec

Fedora's AVR compilers use ccache, so you may have to override some of the paths to the AVR tools in your sketch's Makefile, for example:

```Makefile
OVERRIDE_EXECUTABLES = 1
CC      = /usr/lib64/ccache/$(CC_NAME)
CXX     = /usr/lib64/ccache/$(CXX_NAME)
AS      = /usr/bin/$(AS_NAME)
OBJCOPY = /usr/bin/$(OBJCOPY_NAME)
OBJDUMP = /usr/bin/$(OBJDUMP_NAME)
AR      = /usr/bin/$(AR_NAME)
SIZE    = /usr/bin/$(SIZE_NAME)
NM      = /usr/bin/$(NM_NAME)
```

Or if you don't want to use ccache, then just set ```AVR_TOOLS_PATH=/usr``` and none of the above will be necessary.

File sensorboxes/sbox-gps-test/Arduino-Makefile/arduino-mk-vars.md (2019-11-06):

# Documentation of variables

The following are the different variables that can be overwritten in the user makefiles.

*	[Global variables](#global-variables)
*	[Installation/Directory variables](#installationdirectory-variables)
*	[Arduino IDE variables](#arduino-ide-variables)
*	[Sketch related variables](#sketch-related-variables)
*	[ISP programming variables](#isp-programming-variables)
*	[Compiler/Executable variables](#compilerexecutable-variables)
*	[Avrdude setting variables](#avrdude-setting-variables)
*	[Bootloader variables](#bootloader-variables)
*	[ChipKIT variables](#chipkit-variables)
*	[ARM variables](#arm-variables)
*	[Ctags variables](#ctags-variables)

## Global variables

### ARDUINO_QUIET

**Description:**

Suppress printing of Arduino-Makefile configuration.

Defaults to `0` (unset/disabled).

**Example:**

```Makefile
ARDUINO_QUIET = 1
```

**Requirement:** *Optional*

----

## Installation/Directory variables

### ARDMK_DIR

**Description:**

Directory where the `*.mk` files are stored.

Usually can be auto-detected as parent of `Arduino.mk`.

**Example:**

```Makefile
ARDMK_DIR = /usr/share/arduino
```

**Requirement:** *Optional*

----

### AVR_TOOLS_DIR

**Description:**

Directory where tools such as `avrdude`, `avr-g++`, `avr-gcc`, etc. are stored in the `bin/` subdirectory.

Usually can be auto-detected from `$PATH` as `SYSTEMPATH_AVR_TOOLS_DIR` or as `BUNDLED_AVR_TOOLS_DIR` within the Arduino distribution.

**Example:**

```Makefile
AVR_TOOLS_DIR = /usr
# or
AVR_TOOLS_DIR = /usr/share/arduino/hardware/tools/avr
```

**Requirement:** *Optional*

----

### ARM_TOOLS_DIR

**Description:**

Directory where the arm toolchain is installed. `arm-none-eabi-*` should be
within a /bin subdirectory.

Can usually be detected from `$ARDUINO_PACKAGE_DIR` /tools subdirectory when ARM
device support is installed.

**Example:**

```Makefile
ARM_TOOLS_DIR = /usr
# or
ARM_TOOLS_DIR =
/usr/share/arduino/hardware/tools/arm-none-eabi-gcc/VERSION
```

**Requirement:** *Optional*

----

### RESET_CMD

**Description:**

Command to reset the MCU.

Defaults to `ard-reset-arduino` with the extra `--caterina` flag for atmega32u4 boards.

**Example:**

```Makefile
RESET_CMD = $(HOME)/gertduino/reset
```

**Requirement:** *Optional*

----

## Arduino IDE variables

### ARDUINO_DIR

**Description:**

Directory where the Arduino IDE and/or core files are stored. Usually can be auto-detected as `AUTO_ARDUINO_DIR`.

**Example:**

```Makefile
# Linux
ARDUINO_DIR = /usr/share/arduino
# Mac OS X
ARDUINO_DIR = /Applications/Arduino.app/Contents/Resources/Java
# Mac OSX with IDE 1.5+
ARDUINO_DIR = /Applications/Arduino.app/Contents/Java
```

**Requirement:** *Optional*

----

### ARDUINO_PACKAGE_DIR

**Description:**

Directory where the Arduino package support files are stored. Can auto-detect based on default OS IDE locations.

**Example:**

```Makefile
# Linux
ARDUINO_PACKAGE_DIR = $(HOME)/.arduino15/packages
# Mac OS X
ARDUINO_PACKAGE_DIR = $(HOME)/Library/Arduino15/packages
# Windows
ARDUINO_PACKAGE_DIR = $(USERPROFILE)/AppData/Local/Arduino15/packages
```

**Requirement:** *Optional*

----

### ARDUINO_PLATFORM_LIB_PATH

**Description:**

Directory where the Arduino platform dependent libraries are stored.
(Used only for Arduino 1.5+)

**Example:**

```Makefile
ARDUINO_PLATFORM_LIB_PATH = /usr/share/arduino/hardware/arduino/avr/libraries
```

**Requirement:** *Optional*

----

### ARDUINO_VERSION

**Description:**

Version string for Arduino IDE and/or core.

Usually can be auto-detected as `AUTO_ARDUINO_VERSION` from `/usr/share/arduino/lib/version.txt`

**Example:**

```Makefile
ARDUINO_VERSION = 105
```

**Requirement:** *Optional*

----

### ARCHITECTURE

**Description:**

Architecture for Arduino 1.5+

Defaults to unset for 1.0 or `avr` for 1.5+. This value is not literally the chip architecture but will often be
the chip series within a vendor's 'hardware' folder. For example, will default to `samd` if using Sam.mk.

**Example:**

```Makefile
ARCHITECTURE = arm
```

**Requirement:** *Optional*

----

### ARDMK_VENDOR

**Description:**

Board vendor/maintainer/series.

Defaults to `arduino`.

**Example:**

```Makefile
ARDMK_VENDOR = sparkfun
```

**Requirement:** *Optional*

----

### ARDUINO_SKETCHBOOK

**Description:**

Path to `sketchbook` directory.

Usually can be auto-detected from the Arduino `preferences.txt` file or the default `$(HOME)/sketchbook`

**Example:**

```Makefile
ARDUINO_SKETCHBOOK = $(HOME)/sketches
```

**Requirement:** *Optional*

----

### ARDUINO_PREFERENCES_PATH

**Description:**

Path to Arduino `preferences.txt` file.

Usually can be auto-detected as `AUTO_ARDUINO_PREFERENCES` from the defaults:

*	on Linux (1.0):     `$(HOME)/.arduino/preferences.txt`
*	on Linux (1.5+):    `$(HOME)/.arduino15/preferences.txt`
*	on Mac OS X (1.0):  `$(HOME)/Library/Arduino/preferences.txt`
*	on Mac OS X (1.5+): `$(HOME)/Library/Arduino15/preferences.txt`

**Example:**

```Makefile
ARDUINO_PREFERENCES_PATH = $(HOME)/sketches/preferences.txt
```

**Requirement:** *Optional*

----

### ARDUINO_CORE_PATH

**Description:**

Path to standard Arduino core files.

**Example:**

```Makefile
ARDUINO_CORE_PATH = /usr/share/arduino/hardware/arduino/cores/arduino
```

**Requirement:** *Optional*

----

## Sketch related variables

### ARDUINO_LIBS

**Description:**

Any libraries you intend to include.

Usually can be auto-detected from the sketch. Separated by spaces. If the library has a `/utility` folder (like `SD` or `Wire` library), then the utility folder should also be specified.

**Example:**

```Makefile
ARDUINO_LIBS = SD SD/utility Wire Wire/utility
```

**Requirement:** *Optional*

----

### BOARD_TAG

**Description:**

Device type as listed in `boards.txt` or `make show_boards`.

**Example:**

```Makefile
BOARD_TAG = uno or mega2560
```

**Requirement:** *Mandatory*

----

### BOARD_SUB

**Description:**

1.5+ submenu as listed in `boards.txt` or `make show_submenu`.

**Example:**

```Makefile
# diecimila.name=Arduino Duemilanove or Diecimila
BOARD_TAG=diecimila

# diecimila.menu.cpu.atmega168=ATmega168
BOARD_SUB=atmega168
```

**Requirement:** *Mandatory for 1.5+ if using a submenu CPU*

----

### BOARD_CLOCK

**Description:**

Allow selection of f_cpu and fuses specified in `boards.txt` as `{BOARD_TAG}.menu.clock.{BOARD_CLOCK}`.
This works for microprocessor board definitions like ATtiny that specify not only the clock speed but fuse settings as clock overrides.

It also works for f_cpu values specified in `boards.txt` as `{BOARD_TAG}.menu.speed.{BOARD_CLOCK}`.
For example, the Watterott ATmega328PB library [https://github.com/watterott/ATmega328PB-Testing](https://github.com/watterott/ATmega328PB-Testing).

**Example:**

```Makefile
# Select external 16 MHz clock
BOARD_CLOCK=external16
```

**Example:**
```Makefile
# Select 20MHz speed
BOARD_CLOCK=20mhz
```

**Requirement:** *Optional to override main board f_cpu and/or fuse settings.*

----

### MONITOR_PORT

**Description:**

Path to serial (USB) device used for uploading/serial comms.

**Example:**

```Makefile
# Linux
MONITOR_PORT = /dev/ttyUSB0
# or
MONITOR_PORT = /dev/ttyACM0
# Mac OS X
MONITOR_PORT = /dev/cu.usb*
# Windows
MONITOR_PORT = com3
```

**Requirement:** *Mandatory*

----

### FORCE_MONITOR_PORT

**Description:**

Skip the MONITOR_PORT existance check.

**Example:**

```Makefile
# Enable
FORCE_MONITOR_PORT = true
# Disable (default)
undefine FORCE_MONITOR_PORT
```

**Requirement:** *Optional*

----

### USER_LIB_PATH

**Description:**

Directory where additional libraries are stored.

Defaults to `libraries` directory within user's sketchbook.

**Example:**

```Makefile
# Linux
USER_LIB_PATH = $(HOME)/sketchbook/libraries
# For a random project on *nix
USER_LIB_PATH = /path/to/my/project
```

**Requirement:** *Optional*

----

### OBJDIR

**Description:**

Directory where binaries and compiled files are put.

Defaults to `build-$(BOARD_TAG)` in your `Makefile` directory.

**Example:**

```Makefile
OBJDIR = /path/to/my/project-directory/bin
```

**Requirement:** *Optional*

----

### TARGET

**Description:**

What name you would like for generated target files.

Defaults to the name of your current working directory, but with underscores (_) instead of spaces.

**Example:**

```Makefile
TARGET = my-project
```

Will generate targets like `my-project.hex` and `my-project.elf`.

**Requirement:** *Optional*

----

### ALTERNATE_CORE

**Description:**

Non-standard core for Arduino-unsupported chips like the ATtiny.

**Example:**

```Makefile
# HLT core
ALTERNATE_CORE = attiny-master
# tiny core
ALTERNATE_CORE = arduino-tiny
# tiny core 2
ALTERNATE_CORE = tiny2
```

**Requirement:** *Optional*

----

### ARDUINO_VAR_PATH

**Description:**

Path to non-standard core's variant files.

**Example:**

```Makefile
ARDUINO_VAR_PATH = $(HOME)/sketchbook/hardware/arduino-tiny/cores/tiny
```

**Requirement:** *Optional*

----

### CORE

**Description:**

Name of the core *inside* the ALTERNATE_CORE or the standard core.

Usually can be auto-detected as `build.core` from `boards.txt`.

**Example:**

```Makefile
# standard Arduino core (undefine ALTERNATE_CORE)
CORE = arduino
# or
CORE = robot
# tiny core (ALTERNATE_CORE = arduino-tiny)
CORE = tiny
```

**Requirement:** *Optional*

----

### VARIANT

**Description:**

Variant of a standard board design.

Usually can be auto-detected as `build.variant` from `boards.txt`.

**Example:**

```Makefile
VARIANT = leonardo
```

**Requirement:** *Optional*

----

### USB_TYPE

**Description:**

Define Teensy 3.1 usb device type. Default is USB_SERIAL

**Example:**

```Makefile
USB_TYPE = USB_SERIAL
# or
USB_TYPE = USB_HID
# or
USB_TYPE = USB_SERIAL_HID
# or
USB_TYPE = USB_MIDI
# or
USB_TYPE = USB_RAWHID
# or
USB_TYPE = USB_FLIGHTSIM
```

**Requirement:** *Optional*

----

### USB_VID

**Description:**

Override `USB VID` for atmega32u4 boards.

Usually can be auto-detected as `build.vid` from `boards.txt`

**Example:**

```Makefile
USB_VID = 0x2341
```

**Requirement:** *Optional*

----

### USB_PID

**Description:**

Override `USB PID` for atmega32u4 boards.

Usually can be auto-detected as `build.pid` from `boards.txt`

**Example:**

```Makefile
USB_PID = 0x8039
```

**Requirement:** *Optional*

----

### F_CPU

**Description:**

CPU speed in Hz

Usually can be auto-detected as `build.f_cpu` from `boards.txt`, except in
some 1.5+ cores like attiny where there is a clock submenu.

**Example:**

```Makefile
F_CPU = 8000000L
```

**Requirement:** *Optional*

----

### HEX_MAXIMUM_SIZE

**Description:**

Maximum hex file size

Usually can be auto-detected as `upload.maximum_size` from `boards.txt`

**Example:**

```Makefile
HEX_MAXIMUM_SIZE = 14336
```

**Requirement:** *Optional*

----

### MCU

**Description:**

Microcontroller model.

Usually can be auto-detected as `build.mcu` from `boards.txt`

**Example:**

```Makefile
MCU = atmega32u4
```

**Requirement:** *Optional*

----

### MCU_FLAG_NAME

**Description:**

Override default MCU flags.

Defaults to `mmcu`

**Example:**

```Makefile
MCU_FLAG_NAME = mprocessor
```

**Requirement:** *Optional*

----

### MONITOR_BAUDRATE

**Description:**

Baudrate of the serial monitor.

Defaults to `9600` if it can't find it in the sketch `Serial.begin()`

**Example:**

```Makefile
MONITOR_BAUDRATE = 57600
```

**Requirement:** *Optional*

----

## ISP programming variables

### ISP_PROG

**Description:**

Type of ISP. Either a USB device or ArduinoISP protocol.

**Example:**

```Makefile
ISP_PROG = usbasp
# or
ISP_PROG = usbtiny
# or
ISP_PROG = stk500v2
# or
ISP_PROG = stk500v1
```

**Requirement:** *Optional*

----

### ISP_PORT

**Description:**

Device path to ArduinoISP. Not needed for hardware ISP's. Also used to define
bootloader port on SAMD devices.

**Example:**

```Makefile
# Linux
ISP_PORT = /dev/ttyACM0
```

**Requirement:** *Optional*

----

### ISP_LOCK_FUSE_PRE

**Description:**

Bootloader unlock bits.

Usually can be auto-detected from `boards.txt`

**Example:**

```Makefile
ISP_LOCK_FUSE_PRE = 0x3f
```

**Requirement:** *Optional*

----

### ISP_LOCK_FUSE_POST

**Description:**

Bootloader lock bits.

Usually can be auto-detected from `boards.txt`

**Example:**

```Makefile
ISP_LOCK_FUSE_POST = 0xcf
```

**Requirement:** *Optional*

----

### ISP_HIGH_FUSE

**Description:**

`ISP_LOW_FUSE/ISP_EXT_FUSE` - high/low/extended fuse bits.

Usually can be auto-detected from `boards.txt`

**Example:**

```Makefile
ISP_HIGH_FUSE = 0xdf # or 0xff or 0x01
```

**Requirement:** *Optional*

----

### ISP_EEPROM

**Description:**

Whether to upload the EEPROM file or not.

Defaults to `0`

**Example:**

```Makefile
ISP_EEPROM = 1
```

**Requirement:** *Optional*

----

## Compiler/Executable variables

### CC_NAME

**Description:**

C compiler.

Defaults to `avr-gcc`

**Example:**

```Makefile
CC_NAME = pic32-gcc
```

**Requirement:** *Optional*

----

## Compiler/Executable variables

### TOOL_PREFIX

**Description:**

The tool prefix, which gets prepended to the tools like $(TOOL_PREFIX)-gcc, $(TOOL_PREFIX)-g++, etc.
The following tools will be prefixed with '$(TOOL_PREFIX)-':

   * gcc
   * g++
   * as
   * objcopy
   * objdump
   * ar
   * size
   * nm

Defaults to `avr`

**Example:**

```Makefile
TOOL_PREFIX = arm-none-eabi
TOOL_PREFIX = pic32
```

**Requirement:** *Optional*

----

### CXX_NAME

**Description:**

C++ compiler.

Defaults to `avr-g++`

**Example:**

```Makefile
CXX_NAME = pic32-g++
```

**Requirement:** *Optional*

----

### OBJCOPY_NAME

**Description:**

Objcopy utility.

Defaults to `avr-objcopy`

**Example:**

```Makefile
OBJCOPY_NAME = pic32-objcopy
```

**Requirement:** *Optional*

----

### OBJDUMP_NAME

**Description:**

Objdump utility.

Defaults to `avr-objdump`

**Example:**

```Makefile
OBJDUMP_NAME = pic32-objdump
```

**Requirement:** *Optional*

----

### AR_NAME

**Description:**

Archive utility.

Defaults to `avr-ar` unless you're using toolchain > 4.9.0 in which case we use avr-gcc-ar.

**Example:**

```Makefile
AR_NAME = pic32-ar
```

**Requirement:** *Optional*

----

### SIZE_NAME

**Description:**

Size utility.

Defaults to `avr-size`

**Example:**

```Makefile
SIZE_NAME = pic32-size
```

**Requirement:** *Optional*

----

### NM_NAME

**Description:**

Nm utility.

Defaults to `avr-nm`

**Example:**

```Makefile
NM_NAME = pic32-nm
```

**Requirement:** *Optional*

----

### GDB_NAME

**Description:**

GDB utility.

Defaults to `arm-none-eabi-gdb`

**Requirement:** *Optional*

----

### OPTIMIZATION_LEVEL

**Description:**

Linker's `-O` flag

Defaults to `s`, which shouldn't really be changed as it breaks `SoftwareSerial` and usually results in bigger hex files.

**Example:**

```Makefile
OPTIMIZATION_LEVEL = 3
```

**Requirement:** *Optional*

----

### OTHER_LIBS

**Description:**

Additional Linker lib flags, for platform support

Defaults to ""

**Example:**

```Makefile
OTHER_LIBS = -lsomeplatformlib
```

**Requirement:** *Optional*

----

### CFLAGS_STD

**Description:**

Controls, *exclusively*, which C standard is to be used for compilation.

Defaults to `undefined` on 1.0.x or `-std=gnu11` on 1.5+ or if you install AVR toolchain > 4.9.0

Possible values:

*	With `avr-gcc 4.3`, shipped with the 1.0 Arduino IDE:
	*	`undefined`
	*	`-std=c99`
	*	`-std=gnu89` - This is the default for C code
	*	`-std=gnu99`
*	With `avr-gcc 4.7, 4.8 or 4.9`, installed by you or 1.5+ IDE:
	*	`undefined`
	*	`-std=c99`
	*	`-std=c11`
	*	`-std=gnu89`
	*	`-std=gnu99`
	*	`-std=gnu11` - This is the default for C code

For more information, please refer to the [Options Controlling C Dialect](https://gcc.gnu.org/onlinedocs/gcc/C-Dialect-Options.html)

**Example:**

```Makefile
CFLAGS_STD = -std=gnu89
```

**Requirement:** *Optional*

----

### CXXFLAGS_STD

**Description:**

Controls, *exclusively*, which C++ standard is to be used for compilation.

Defaults to `undefined` on 1.0 or `-std=gnu++11` on AVR toolchain > 4.9.0 (e.g. IDE 1.6.10+)

Possible values:

*	With `avr-gcc 4.3`, shipped with the 1.0 Arduino IDE:
	*	`undefined`
	*	`-std=c++98`
	*	`-std=c++0x`
	*	`-std=gnu++98` - This is the default for C code
	*	`-std=gnu++0x`
*	With `avr-gcc 4.7, 4.8 or 4.9`, installed by you or 1.5+ IDE:
	*	`undefined`
	*	`-std=c++98`
	*	`-std=c++11`
	*	`-std=c++1y`
	*	`-std=c++14`
	*	`-std=gnu++98`
	*	`-std=gnu++11` - This is the default for C++ code
	*	`-std=gnu++1y`
	*	`-std=gnu++14`

For more information, please refer to the [Options Controlling C Dialect](https://gcc.gnu.org/onlinedocs/gcc/C-Dialect-Options.html)

**Example:**

```Makefile
CXXFLAGS_STD = -std=gnu++98
```

**Requirement:** *Optional*

----

### CFLAGS

**Description:**

Flags passed to compiler for files compiled as C. Add more flags to this
variable using `+=`.

Defaults to `undefined` on 1.0 or `-flto -fno-fat-lto-objects -fdiagnostics-color=$(DIAGNOSTICS_COLOR_WHEN)` on AVR toolchain > 4.9.0 (e.g. IDE 1.6.10+)

**Example:**

```Makefile
CFLAGS += -my-c-only-flag
```

**Requirement:** *Optional*

----

### CXXFLAGS

**Description:**

Flags passed to the compiler for files compiled as C++. Add more flags to this
variable using `+=`.

Defaults to `-fpermissive -fno-exceptions` on 1.0
or `-fpermissive -fno-exceptions -fno-threadsafe-statics -flto -fno-devirtualize -fdiagnostics-color`
on AVR toolchain > 4.9.0 (e.g. IDE 1.6.10+)

**Example:**

```Makefile
CXXFLAGS += -my-c++-onlyflag
```

**Requirement:** *Optional*

----

### DIAGNOSTICS_COLOR_WHEN

**Description:**

This variable controls the compiler's diagnostics-color setting, as defined
in CFLAGS or CXXFLAGS, on AVR toolchain > 4.9.0.
Supported values are: `always`, `never` and `auto`.
For more details, see: [Options to Control Diagnostic Messages Formatting]
(https://gcc.gnu.org/onlinedocs/gcc-4.9.2/gcc/Language-Independent-Options.html#Language-Independent-Options)

Defaults to `always`.

**Example:**

```Makefile
DIAGNOSTICS_COLOR_WHEN = never
# or
DIAGNOSTICS_COLOR_WHEN = auto
```

**Requirement:** *Optional*

----

### ASFLAGS

**Description:**

Flags passed to compiler for files compiled as assembly (e.g. `.S` files). Add
more flags to this variable using `+=`.

Defaults to all flags required for a typical build.

**Example:**

```Makefile
ASFLAGS += -my-as-only-flag
```

**Requirement:** *Optional*

----

### CPPFLAGS

**Description:**

Flags passed to the C pre-processor (for C, C++ and assembly source files). Add
more flags to this variable using `+=`.

Defaults to all flags required for a typical build.

**Example:**

```Makefile
CPPFLAGS += -DMY_DEFINE_FOR_ALL_SOURCE_TYPES
```

**Requirement:** *Optional*

----

### OVERRIDE_EXECUTABLES

**Description:**

Override the default build tool paths and names.

If OVERRIDE_EXECUTABLES is defined, all tools (`CC`, `CXX`, `AS`,
`OBJCOPY`, `OBJDUMP`, `AR`, `SIZE`, `NM`) must have their paths
explicitly defined. This may be used in the rare case where
overriding a path and/or executable name is required.
The "?=" assignment cannot be used because the executable tags
are already implicitly defined by Make (e.g. $(CC) == cc).

**Example:**

```Makefile
OVERRIDE_EXECUTABLES = 1
CC      = /usr/bin/avr-gcc
CXX     = /usr/bin/avr-g++
AS      = /usr/bin/avr-as
OBJCOPY = /usr/bin/avr-objcopy
OBJDUMP = /usr/bin/avr-objdump
AR      = /usr/bin/avr-ar
SIZE    = /some_path/alternative_avr-size
NM      = /some_path/alternative_avr-nm
```

**Requirement:** *Optional*

----

### MONITOR_CMD

**Description:**

Command to run the serial monitor.

Defaults to `screen`

**Example:**

```Makefile
MONITOR_CMD = minicom
```

**Requirement:** *Optional*

----

### MONITOR_PARAMS

**Description:**

Additional parameters for the putty -sercfg command line argument.

Interpreted as a comma-separated list of configuration options.

**Example:**

```Makefile
MONITOR_PARAMS = 8,1,n,N
```

**Requirement:** *Optional*

----

### PRE_BUILD_HOOK

**Description:**

Path to shell script to be executed before build. Could be used to automatically
bump revision number for example.

Defaults to `pre-build-hook.sh`

**Example:**

```Makefile
PRE_BUILD_HOOK = $(HOME)/bin/bump-revision.sh
```

**Requirement:** *Optional*

----

## Avrdude setting variables

### AVRDUDE

**Description:**

Path to `avrdude` utility

Usually can be auto-detected within the parent of `AVR_TOOLS_DIR` or in the `$PATH`

**Example:**

```Makefile
AVRDUDE = /usr/bin/avrdude
```

**Requirement:** *Optional*

----

### AVRDUDE_CONF

**Description:**

Path to `avrdude.conf` file

Usually can be auto-detected within the parent of `AVR_TOOLS_DIR`

**Example:**

```Makefile
AVRDUDE_CONF = /etc/avrdude.conf
# or
AVRDUDE_CONF = /usr/share/arduino/hardware/tools/avrdude.conf
```

**Requirement:** *Optional*

----

### AVRDUDE_AUTOERASE_FLASH

**Description:**

Enable autoerase flash.

By default disabled.

**Example:**

```Makefile
AVRDUDE_AUTOERASE_FLASH = yes
```

**Requirement:** *Optional*

----

### AVR_TOOLS_PATH

**Description:**

Directory where tools such as `avrdude`, `avr-g++`, `avr-gcc` etc. are stored.

Usually can be auto-detected from `AVR_TOOLS_DIR/bin`

**Example:**

```Makefile
AVR_TOOLS_PATH = /usr/bin
# or
AVR_TOOLS_PATH = /usr/share/arduino/hardware/tools/avr/bin
```

**Requirement:** *Optional*

----

### ARDUINO_LIB_PATH

**Description:**

Directory where the standard Arduino libraries are stored.

Defaults to `ARDUINO_DIR/libraries`

**Example:**

```Makefile
# Linux
ARDUINO_LIB_PATH = /usr/share/arduino/libraries
```

**Requirement:** *Optional*

----

### ARDUINO_CORE_PATH

**Description:**

Directory where the standard Arduino cores are stored.

Defaults to `ARDUINO_DIR/hardware/arduino/cores/arduino`

**Example:**

```Makefile
ARDUINO_CORE_PATH = /usr/share/arduino/hardware/arduino/cores/robot
```

**Requirement:** *Optional*

----

### ALTERNATE_CORE_PATH

**Description:**

Path to non-standard cores.

Defaults to `ARDUINO_SKETCHBOOK/hardware/ALTERNATE_CORE`

**Example:**

```Makefile
ALTERNATE_CORE_PATH = $(HOME)/sketchbook/hardware/arduino-tiny/cores/tiny
```

**Requirement:** *Optional*

----

### CORE_VER

**Description:**

Alternate core release version. The Arduino board support packages are within
a sub-directory indicated by this define.

Defaults to package current release.

**Example:**

```Makefile
CORE_VER = 1.6.17
```

**Requirement:** *Optional*

----

### CMSIS_DIR

**Description:**

Path to ARM CMSIS. Normally installed as part of ARM  board support.

Defaults to `ARDUINO_PACKAGE_DIR/tools/CMSIS/4.5.0/CMSIS`

**Example:**

```Makefile
CMSIS_DIR = /usr/share/CMSIS
```

**Requirement:** *Optional*

----

### CMSIS_ATMEL_DIR

**Description:**

Path to CMSIS-Atmel directory. Installed with ARM support package.

Defaults to `ARDUINO_PACKAGE_DIR/tools/CMSIS-Atmel/1.1.0/CMSIS`

**Requirement:** *Optional*
----

### BOARDS_TXT

**Description:**

Path to `boards.txt`

Defaults to `ARDUINO_DIR/hardware/arduino/boards.txt`

**Example:**

```Makefile
BOARD_TXT = $(HOME)/sketchbook/hardware/boards.txt
# or
BOARD_TXT = /usr/share/arduino/hardware/arduino/boards.txt
```

**Requirement:** *Optional*

----

### AVRDUDE_ARD_BAUDRATE

**Description:**

Upload speed

Usually can be auto-detected as `upload.speed` from `boards.txt`

**Example:**

```Makefile
AVRDUDE_ARD_BAUDRATE = 19200
```

**Requirement:** *Optional*

----

### AVRDUDE_ARD_PROGRAMMER

**Description:**

Upload protocol

Usually can be auto-detected as `upload.protocol` from `boards.txt`

**Example:**

```Makefile
AVRDUDE_ARD_PROGRAMMER = stk500v1
```

**Requirement:** *Optional*

----

### AVRDUDE_ISP_BAUDRATE

**Description:**

ISP speed if different to `upload.speed`

Defaults to same as `AVRDUDE_ARD_BAUDRATE` or `19200`

**Example:**

```Makefile
AVRDUDE_ISP_BAUDRATE = 19200
```

**Requirement:** *Optional*

----

### AVRDUDE_OPTS

**Description:**

Options to pass to `avrdude`.

Defaults to `-q -V` (quiet, don't verify). User values are not *ANDed* to the defaults, you have to set each option you require.

**Example:**

```Makefile
AVRDUDE_OPTS = -v
```

**Requirement:** *Optional*

----

## Bootloader variables

### BOOTLOADER_FILE

**Description:**

File for bootloader.

Usually can be auto-detected as `bootloader.file` from `boards.txt`

**Example:**

```Makefile
BOOTLOADER_FILE = optiboot_atmega328.hex
```

**Requirement:** *Optional*

----

### BOOTLOADER_PATH

**Description:**

Relative path to bootloader directory.

Usually can be auto-detected as a relative `bootloader.path` from `boards.txt`

Deprecated in 1.5, now part of bootloader.file

**Example:**

```Makefile
BOOTLOADER_PATH = optiboot
# or
BOOTLOADER_PATH = arduino:atmega
```

**Requirement:** *Optional*

----

### BOOTLOADER_PARENT

**Description:**

Absolute path to bootloader file's parent directory.

Defaults to `/usr/share/arduino/hardware/arduino/bootloaders` (Linux)

**Example:**

```Makefile
BOOTLOADER_PARENT = $(HOME)/sketchbook/hardware/promicro/bootloaders
BOOTLOADER_PATH  = caterina
BOOTLOADER_FILE  = Caterina-promicro16.hex
```

Would result in an absolute path to the bootloader hex file of `$(HOME)/sketchbook/hardware/promicro/bootloaders/caterina/Caterina-promicro16.hex`

**Requirement:** *Optional, unless BOOTLOADER_FILE and/or BOOTLOADER_PATH are user-defined*

----

### BOOTLOADER_SIZE

**Description:**

Size of bootloader on ARM devices, ensures correct start address when flashing
application area. Normally parsed from boards.txt

Defaults to `0x2000`

**Requirement:** *Optional*

----

### BOOTLOADER_UNPROTECT

**Description:**

Bootloader unprotect sequence for upload tool. Normally parsed from boards.txt

Defaults to `at91samd bootloader 0`

**Requirement:** *Optional*

----

### BOOTLOADER_PROTECT

**Description:**

Bootloader protect sequence for upload tool. Normally parsed from boards.txt

Defaults to `at91samd bootloader 16384`

**Requirement:** *Optional*

----

### BOOTLOADER_PROTECT_VERIFY

**Description:**

Bootloader protect and verify  sequence for upload tool. Normally parsed from boards.txt

Defaults to `at91samd bootloader`

**Requirement:** *Optional*

----

### BOOTLOADER_UPLOAD_TOOL

**Description:**

Bootloader upload binary to use. Normally parsed from boards.txt.

Defaults to `openocd`

**Requirement:** *Optional*

----

## ChipKIT variables

### MPIDE_DIR

**Description:**

Path to chipKIT MP IDE

Usually can be auto-detected as `AUTO_MPIDE_DIR` from the defaults `/usr/share/mpide` (Linux) or `/Applications/Mpide.app/Contents/Resources/Java` (OSX)

**Example:**

```Makefile
MPIDE_DIR = $(HOME)/mpide
```

**Requirement:** *Optional*

----

### MPIDE_PREFERENCES_PATH

**Description:**

Path to chipKIT `preferences.txt` file.

Usually can be auto-detected as `AUTO_MPIDE_PREFERENCES_PATH` from the defaults `$(HOME)/.mpide/preferences.txt` (Linux) or `$(HOME)/Library/Mpide/preferences.txt` (OSX)

**Example:**

```Makefile
MPIDE_PREFERENCES_PATH = $(HOME)/chipkit/preferences.txt
```

**Requirement:** *Optional*

----

## ARM variables

### UPLOAD_TOOL

**Description:**

Tool to upload binary to device. Normally parsed from boards.txt.

Defaults to `openocd`

**Example:**

```Makefile
UPLOAD_TOOL = gdb
```

**Requirement:** *Optional*

----

### DEBUG

**Description:**

Define to set `DEBUG_FLAGS` and allow stepping of code using GDB.

Defaults to undefined.

**Example:**

```Makefile
DEBUG = 1
```

**Requirement:** *Optional*

----

### GDB_PORT

**Description:**

Server port to use for GDB debugging or upload. Default assumes server running
on localhost but can re-define to use Black Magic Probe serial port.

Defaults to `localhost:3333`

**Example:**

```Makefile
GDB_PORT = /dev/ttyACM0
```

**Requirement:** *Optional*

----

### GDB_OPTS

**Description:**

Optional arguments to parse to GDB command.

Defaults to `-ex "target extended-remote $(GDB_PORT)" -ex "monitor swdp_scan" -ex "attach 1" -ex "load" -d $(OBJDIR) $(TARGET_ELF)`

**Requirement:** *Optional*

----

### GDB_UPLOAD_OPTS

**Description:**

Optional arguments to parse to GDB command when uploading binary only.

Defaults to `GDB_UPLOAD_OPTS = $(GDB_OPTS) -ex "set confirm off" -ex "set target-async off" -ex "set remotetimeout 30" -ex "detach" -ex "kill" -ex "quit"`

**Requirement:** *Optional*

----

### BOSSA

**Description:**

Path to bossac binary.

Can usually be detected from `$ARDUINO_PACKAGE_DIR` /tools subdirectory when ARM
device support is installed.

**Requirement:** *Optional*

----

### BOSSA_OPTS

**Description:**

Flags to pass to bossac command.

Defaults to `-d --info --erase --write --verify --reset`

**Requirement:** *Optional*

----

### OPENOCD

**Description:**

Path to openocd binary.

Can usually be detected from `$ARDUINO_PACKAGE_DIR` /tools subdirectory when ARM
device support is installed.

**Requirement:** *Optional*

----

### OPENOCD_OPTS

**Description:**

Flags to pass to openocd command. If using openocd from non-Arduino
distributions, one should define this with the path to the Arduino openocd script.

Defaults to `-d2`

Example:

```Makefile
OPENOCD_OPTS = $(ARDUINO_PACKAGE_DIR)/$(ARDMK_VENDOR)/tools/openocd/0.9.0-arduino6-static/share/openocd/scripts/ -f $(ARDUINO_PACKAGE_DIR)/$(ARDMK_VENDOR)/hardware/samd/1.6.17/variants/$(VARIANT)/$(OPENOCD_SCRIPT) 
```

**Requirement:** *Optional*

----

## Ctags variables

### TAGS_FILE

**Description:**

Output file name for tags. Defaults to 'tags'.

**Example:**

```Makefile
TAGS_FILE = .tags
```

**Requirement:** *Optional*

----

### CTAGS_OPTS

**Description:**

Additional options to pass to `ctags` command.

**Example:**

```Makefile
# Run ctags in verbose mode
CTAGS_OPTS = -V
```

**Requirement:** *Optional*

----

### CTAGS_CMD

**Description:**

Location of `ctags` binary. Defaults to user path.

**Example:**

```Makefile
CTAGS_CMD = /usr/local/bin/
```

**Requirement:** *Optional*

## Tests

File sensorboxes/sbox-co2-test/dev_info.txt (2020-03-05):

DEVICE INFO
-----------
DEV_name = bilbo
DEV_mac = 
DEV_clock = 160
DEV_ID = sbox-co2-tester
LOC = loc0

SENSOR1 = SCD30 (CO2)
SENSOR2 = SGP30 (eCO2)
SENSOR3 = BME680 (eCO2)

SENSOR1_TOPIC   "/sensornet/loc0/co2-a"
SENSOR2_TOPIC   "/sensornet/loc0/co2-b"
SENSOR3_TOPIC   "/sensornet/loc0/co2-c"

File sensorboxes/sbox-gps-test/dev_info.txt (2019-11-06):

DEVICE INFO
-----------
DEV_name = mendes 
DEV_mac = ASKME
DEV_clock = 
DEV_ID = sbox0
LOC = undefined

SENSOR1 = PMS7003 (pm2.5, pm10)
SENSOR2 = Sensiron SCD30 (CO2, temp, humidity)

SENSOR1_TOPIC   ""

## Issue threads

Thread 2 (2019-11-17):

SCD Idle Power Draw

thejimster82, 2019-11-17:
When the SCD is connected and taking readings, it increases idle power draw by about 4.3mA. When it is immediately disabled via sending 0x0104 on the I2C bus in setup() this is not an issue. However, when it is disabled and then re-enabled and read from and then disabled again, the current draw never goes back down. Could solve with a MOSFET or BJT if space allows.

unixjazz, 2021-09-14:
The datasheet describes a self-calibration period in which the sensor needs to stay on. By turning it on and off, we have to redo the self-calibration. I would suggest just increasing the sampling frequency (by a lot), so there is some power saving. This is also described in the data sheet for achieving lower power modes with the SCD30. Otherwise, it is better to rely on other sensors for low-power applications.

Closing this issue and marking as "work as designed" (except for the curious behavior you describe, which, I guess is something to be fixed in the firmware of the MCU that is shipped with the sensor itself).

Closed 2021-09-14.

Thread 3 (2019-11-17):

PMS Idle Power Draw

thejimster82, 2019-11-17:
The Feather M0 LoRa draws about 0.37mA of current in idle. When the PMS is connected and the RESET held high, it runs at 1.7mA. If we could instead disconnect power from the PMS entirely using a MOSFET or BJT, we might be able to save that little bit of power and significantly increase the battery life of the device.

unixjazz, 2021-07-02:
Works as designed: the solution where would be to pick a low-power sensor.

Closed 2021-07-02.

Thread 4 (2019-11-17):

Optimal LoRa Radio Settings

thejimster82, 2019-11-17:
Right now, the LoRa radio reaches 130mA of current when sending packets. It is possible to change the parameters on the radio in a way that might reduce this current draw, especially in the circumstance that the user is very close to their gateway.

unixjazz, 2020-01-13:
If the sensor box is closer to the gateway, the LMIC library allows for changing the TX power:
```
    // Set the transmission power (0 - 14):
    LMIC_setDrTxpow(DR_SF7, 0);
```

Closed 2020-03-05.

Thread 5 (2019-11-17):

Feather M0 Idle Power Draw

thejimster82, 2019-11-17:
The Feather M0 LoRa draws about 0.37mA of current when idling using the sleepydog library. It would be ideal if we could push this down much further to the 0.01 or even 0.001 mA range and we should begin to explore other methods for doing this or other boards entirely that will be able to go lower than the m0 can possibly go.

unixjazz, 2020-01-13:
The Feather M0 is not meant for low-power applications: because of the circuitry for the external battery, the LDO, and the peripherals we might not be able to bring it lower than 300uA in sleep mode.

krad246, 2020-01-13:
Which board do we have? Probably should spend some time looking at where the power draws are coming from in the first place.

Where's the power measurement coming from? VCC? If so, then that current may be going somewhere else.

This is the schematic of the Feather M0 LoRA, unless I'm mistaken

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

Inspecting the schematic, I see that the LDO is in the direct path. If you're measuring on the input side, then you're also measuring the ~90 uA quiescent current from it.

Looking at table 37-10 from [ATSAMD21G18 datasheet](http://ww1.microchip.com/downloads/en/DeviceDoc/SAMD21-Family-DataSheet-DS40001882D.pdf), the standby current is worst case ~15 uA.

Looking at the actual LoRa chip behavior suggests that it doesn't matter in the best case.

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

Evidently there is still like 200 uA that isn't accounted for... need to characterize it by checking the paths really.

unixjazz, 2020-01-13:
As I mentioned above: the culprits may be the battery charging IC and the LDO. We can still try to squeeze a few uA out, though. The MCU itself is not the issue here, but the Feather M0 board.

unixjazz, 2020-02-19:
closing this as the Feather M0 ** works as designed. **

Closed 2020-02-19.

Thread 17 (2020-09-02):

Finish schematics review

unixjazz, 2020-09-02:
Pending the final review of the schematics:

- SAML21 pinout
- KiCad footprints
- Include data sheets / partnumbers
- 3D models for kicad

Closed 2021-07-02.

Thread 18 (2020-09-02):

Finish board layout / routing

unixjazz, 2020-09-02:
Work on board layout has started, routing is pending for the Big Dot board.
This task depends on the issue #17

Closed 2020-09-28.

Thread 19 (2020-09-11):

Find larger SMD footprints

vnl6rj, 2020-09-11:
To make sure that the kit is accessible to people just learning to do SMD soldering, we can ensure that we use large parts where possible, and also expand the size of the pads.

unixjazz, 2020-11-11:
LTC4070 is pretty darn good IC, but it is: 1) expensive; 2) harder to solder; 3) harder to find.  I would suggest finding a substitute, so the kit becomes more accessible.

Closed 2020-09-28.

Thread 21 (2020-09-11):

Optimize PCB size and shape

vnl6rj, 2020-09-11:
While having a circular PCB is very cool, it also means that there is a lot of wastage wherever there are no components. This may be remedied by choosing a more space-efficient board shape and size.

However, the board should still be easy to solder on, which means that it cannot be too small or dense.

Closed 2020-09-28.

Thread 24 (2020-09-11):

Test I2C, UART, other serial

vnl6rj, 2020-09-11:
Most sensors will connect using these protocols, so they must be tested functional.

unixjazz, 2021-07-02:
done.

Closed 2021-07-02.

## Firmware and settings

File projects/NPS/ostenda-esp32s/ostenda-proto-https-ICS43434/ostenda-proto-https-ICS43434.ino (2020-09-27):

/*
 * Ostenda proto, v.0.5
 * 
 * DEV_name = "ESP32S"
 * DEV_ID = "esp32s-a1"
 * LOC = loc0
 * TOPIC = ostenda0/tree1/dbA
 *  
 * SENSOR1 = ICS43434
 *   
 * Dependencies: FastLED v3.3, PubSub v2.8
 * 
 * Contains ESP32 + I2S microphone capture code from:
 * "Display A-weighted sound level measured by I2S Microphone"
 * (c)2019 Ivan Kostoski
 *
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
 * See AUTHORS and LICENSE files for more details
 *
 */
 
#include <WiFiClientSecure.h>
#include <PubSubClient.h>
#include "private_settings.h"
#include <FastLED.h>
#include <driver/i2s.h>
#include "sos-iir-filter.h"

// ESP32-S blue || red LED
#define LED_BUILTIN 13

// LED strip conf
#define DATA_PIN           4          // MOSI on Huzzah32
#define LED_TYPE           WS2812B    // If you use Neopixels
#define COLOR_ORDER        GRB        //
#define NUM_LEDS           40         // number of LEDs
#define FRAMES_PER_SECOND  120        // redefine if needed
#define BRIGHTNESS         5         // set initial brightness: 2% (0 - 255)

// Mic conf
#define LEQ_PERIOD        1           // second(s)
#define WEIGHTING         C_weighting // Options: 'C_weighting' or 'None' (Z_weighting)
#define LEQ_UNITS         "LAeq"      // customize based on above weighting used
#define DB_UNITS          "dBA"       // customize based on above weighting used

// NOTE: Some microphones require at least DC-Blocker filter
#define MIC_EQUALIZER     ICS43434    // See below for defined IIR filters or set to 'None' to disable
#define MIC_OFFSET_DB     3.0103      // Default offset (sine-wave RMS vs. dBFS). Modify this value for linear calibration

// Customize these values from microphone datasheet
#define MIC_SENSITIVITY   -26         // dBFS value expected at MIC_REF_DB (Sensitivity value from datasheet)
#define MIC_REF_DB        94.0        // Value at which point sensitivity is specified in datasheet (dB)
#define MIC_OVERLOAD_DB   116.0       // dB - Acoustic overload point
#define MIC_NOISE_DB      29          // dB - Noise floor
#define MIC_BITS          24          // valid number of bits in I2S data
#define MIC_CONVERT(s)    (s >> (SAMPLE_BITS - MIC_BITS))
#define MIC_TIMING_SHIFT  0           // Set to one to fix MSB timing for some microphones, i.e. SPH0645LM4H-x

// Calculate reference amplitude value at compile time
constexpr double MIC_REF_AMPL = pow(10, double(MIC_SENSITIVITY)/20) * ((1<<(MIC_BITS-1))-1);

// I2S pins - Can be routed to almost any (unused) ESP32 pin.
//            SD can be any pin, including input only pins (36-39).
//            SCK (i.e. BCLK) and WS (i.e. L/R CLK) must be output capable pins
#define I2S_WS            27 
#define I2S_SCK           14
#define I2S_SD            21

// I2S peripheral to use (0 or 1)
#define I2S_PORT          I2S_NUM_0

// IIR Filters
// DC-Blocker filter - removes DC component from I2S data
// See: https://www.dsprelated.com/freebooks/filters/DC_Blocker.html
// a1 = -0.9992 should heavily attenuate frequencies below 10Hz
SOS_IIR_Filter DC_BLOCKER = { 
  gain: 1.0,
  sos: {{-1.0, 0.0, +0.9992, 0}}
};

// Equalizer IIR filters to flatten microphone frequency response
// TDK/InvenSense ICS-43434
// Datasheet: https://www.invensense.com/wp-content/uploads/2016/02/DS-000069-ICS-43434-v1.1.pdf
// B = [0.477326418836803, -0.486486982406126, -0.336455844522277, 0.234624646917202, 0.111023257388606];
// A = [1.0, -1.93073383849136326, 0.86519456089576796, 0.06442838283825100, 0.00111249298800616];
SOS_IIR_Filter ICS43434 = { 
  gain: 0.477326418836803,
  sos: { // Second-Order Sections {b1, b2, -a1, -a2}
   {+0.96986791463971267, 0.23515976355743193, -0.06681948004769928, -0.00111521990688128},
   {-1.98905931743624453, 0.98908924206960169, +1.99755331853906037, -0.99755481510122113}
  }
};

// Knowles SPH0645LM4H-B, rev. B
// https://cdn-shop.adafruit.com/product-files/3421/i2S+Datasheet.PDF
// B ~= [1.001234, -1.991352, 0.990149]
// A ~= [1.0, -1.993853, 0.993863]
// With additional DC blocking component
SOS_IIR_Filter SPH0645LM4H_B_RB = {
  gain: 1.00123377961525, 
  sos: { // Second-Order Sections {b1, b2, -a1, -a2}
    {-1.0, 0.0, +0.9992, 0}, // DC blocker, a1 = -0.9992
    {-1.988897663539382, +0.988928479008099, +1.993853376183491, -0.993862821429572}
  }
};

// Weighting filters
// A-weighting IIR Filter, Fs = 48KHz 
// (By Dr. Matt L., Source: https://dsp.stackexchange.com/a/36122)
// B = [0.169994948147430, 0.280415310498794, -1.120574766348363, 0.131562559965936, 0.974153561246036, -0.282740857326553, -0.152810756202003]
// A = [1.0, -2.12979364760736134, 0.42996125885751674, 1.62132698199721426, -0.96669962900852902, 0.00121015844426781, 0.04400300696788968]
SOS_IIR_Filter A_weighting = {
  gain: 0.169994948147430, 
  sos: { // Second-Order Sections {b1, b2, -a1, -a2}
    {-2.00026996133106, +1.00027056142719, -1.060868438509278, -0.163987445885926},
    {+4.35912384203144, +3.09120265783884, +1.208419926363593, -0.273166998428332},
    {-0.70930303489759, -0.29071868393580, +1.982242159753048, -0.982298594928989}
  }
};

// C-weighting IIR Filter, Fs = 48KHz 
// Designed by invfreqz curve-fitting, see respective .m file
// B = [-0.49164716933714026, 0.14844753846498662, 0.74117815661529129, -0.03281878334039314, -0.29709276192593875, -0.06442545322197900, -0.00364152725482682]
// A = [1.0, -1.0325358998928318, -0.9524000181023488, 0.8936404694728326   0.2256286147169398  -0.1499917107550188, 0.0156718181681081]
SOS_IIR_Filter C_weighting = {
  gain: -0.491647169337140,
  sos: { 
    {+1.4604385758204708, +0.5275070373815286, +1.9946144559930252, -0.9946217070140883},
    {+0.2376222404939509, +0.0140411206016894, -1.3396585608422749, -0.4421457807694559},
    {-2.0000000000000000, +1.0000000000000000, +0.3775800047420818, -0.0356365756680430}
  }
};

// Sampling
#define SAMPLE_RATE       48000 // Hz, fixed to design of IIR filters
#define SAMPLE_BITS       32    // bits
#define SAMPLE_T          int32_t 
#define SAMPLES_SHORT     (SAMPLE_RATE / 8) // ~125ms
#define SAMPLES_LEQ       (SAMPLE_RATE * LEQ_PERIOD)
#define DMA_BANK_SIZE     (SAMPLES_SHORT / 16)
#define DMA_BANKS         32

// Data we push to 'samples_queue'
struct sum_queue_t {
  // Sum of squares of mic samples, after Equalizer filter
  float sum_sqr_SPL;
  // Sum of squares of weighted mic samples
  float sum_sqr_weighted;
  // Debug only, FreeRTOS ticks we spent processing the I2S data
  uint32_t proc_ticks;
};
QueueHandle_t samples_queue;

// Static buffer for block of samples
float samples[SAMPLES_SHORT] __attribute__((aligned(4)));

// I2S Microphone sampling setup 
void mic_i2s_init() {
  const i2s_config_t i2s_config = {
    mode: i2s_mode_t(I2S_MODE_MASTER | I2S_MODE_RX),
    sample_rate: SAMPLE_RATE,
    bits_per_sample: i2s_bits_per_sample_t(SAMPLE_BITS),
    channel_format: I2S_CHANNEL_FMT_ONLY_LEFT,
    communication_format: i2s_comm_format_t(I2S_COMM_FORMAT_I2S | I2S_COMM_FORMAT_I2S_MSB),
    intr_alloc_flags: ESP_INTR_FLAG_LEVEL1,
    dma_buf_count: DMA_BANKS,
    dma_buf_len: DMA_BANK_SIZE,
    use_apll: true,
    tx_desc_auto_clear: false,
    fixed_mclk: 0
  };
  // I2S pin mapping
  const i2s_pin_config_t pin_config = {
    bck_io_num:   I2S_SCK,  
    ws_io_num:    I2S_WS,    
    data_out_num: -1, // not used
    data_in_num:  I2S_SD   
  };

  i2s_driver_install(I2S_PORT, &i2s_config, 0, NULL);

  #if (MIC_TIMING_SHIFT > 0) 
    // Undocumented (?!) manipulation of I2S peripheral registers
    // to fix MSB timing issues with some I2S microphones
    REG_SET_BIT(I2S_TIMING_REG(I2S_PORT), BIT(9));   
    REG_SET_BIT(I2S_CONF_REG(I2S_PORT), I2S_RX_MSB_SHIFT);  
  #endif
  
  i2s_set_pin(I2S_PORT, &pin_config);
}

// I2S Reader Task
// FreeRTOS priority and stack size (in 32-bit words) 
#define I2S_TASK_PRI   4
#define I2S_TASK_STACK 2048

void mic_i2s_reader_task(void* parameter) {
  mic_i2s_init();

  // Discard first block, microphone may have startup time (i.e. INMP441 up to 83ms)
  size_t bytes_read = 0;
  i2s_read(I2S_PORT, &samples, SAMPLES_SHORT * sizeof(int32_t), &bytes_read, portMAX_DELAY);

  while (true) {
    // Block and wait for microphone values from I2S
    i2s_read(I2S_PORT, &samples, SAMPLES_SHORT * sizeof(SAMPLE_T), &bytes_read, portMAX_DELAY);

    TickType_t start_tick = xTaskGetTickCount();
    
    // Convert (including shifting) integer microphone values to floats, 
    // using the same buffer (assumed sample size is same as size of float), 
    // to save a bit of memory
    SAMPLE_T* int_samples = (SAMPLE_T*)&samples;
    for(int i=0; i<SAMPLES_SHORT; i++) samples[i] = MIC_CONVERT(int_samples[i]);

    sum_queue_t q;

    // Apply equalization and calculate Z-weighted sum of squares, 
    // writes filtered samples back to the same buffer.
    q.sum_sqr_SPL = MIC_EQUALIZER.filter(samples, samples, SAMPLES_SHORT);

    // Apply weighting and calucate weigthed sum of squares
    q.sum_sqr_weighted = WEIGHTING.filter(samples, samples, SAMPLES_SHORT);

    // Debug only. Ticks we spent filtering and summing block of I2S data
    //q.proc_ticks = xTaskGetTickCount() - start_tick;

    // Send the sums to FreeRTOS queue where main task will pick them up
    // and further calcualte decibel values (division, logarithms, etc...)
    xQueueSend(samples_queue, &q, portMAX_DELAY);
  }
}

// MQTT constants
char tempString[8];  // temp_var
long now;            // temp_var
int last_msg;        // temp_var

// stored certs
//X509List cert(ca_root);

WiFiClientSecure ESPclient;
PubSubClient client(ESPclient);

// define MQTT topics
#define SENSOR1_TOPIC   "/ostenda0/tree5/dBA"

void mqtt_connect() {
  Serial.println("MQTT connecting...");
  String clientId = "ESPClient";
  if (client.connect(mqtt_clientID, mqtt_user, mqtt_passwd)) {
    Serial.println("Connected to MQTT server");
    //client.subscribe(SENSOR1_TOPIC);
  } else {
    Serial.print("Connection failed, status code = ");
    Serial.print(client.state());
  }
} 

// Callback for MQTT msgs, unused for now
//void receivedCallback(char* topic, byte* payload, unsigned int length) {
//  Serial.print("Message received: ");
//  Serial.println(topic);
//  Serial.print("Payload: ");
//  for (int i = 0; i < length; i++) {
//    Serial.print((char)payload[i]);
//  }
//  Serial.println();
//}

// WiFi
void WiFi_connect() {
  WiFi.disconnect(true);
  WiFi.begin(ssid, passwd);
  delay(5000);
  
  if (WiFi.status() == WL_CONNECTED) {
    Serial.println("");
    Serial.println("WiFi connected");
    Serial.println("IP address: ");
    Serial.println(WiFi.localIP());
    digitalWrite(LED_BUILTIN, LOW);
  }
}

// LED vars + fade function
CRGB leds[NUM_LEDS];
int fadeVal = 0;
int currentBright = BRIGHTNESS;

// func: LED_fade(R, fade value, current brightness)
void LED_fade(int led_color, int fadeVal, int currentBright) {
  if (fadeVal > currentBright) {
    // fade in
    while (currentBright < fadeVal) {
      currentBright++;
      // CHSV(hue, saturation, value)
      // CRGB(r, g, b)
      //for (int i = 0; i < NUM_LEDS; i++) {
      //  leds[i] = CHSV(0, led_color, 255);
        //leds[i] = CRGB(led_color, 255, 250);
      //}
      FastLED.setBrightness(currentBright);
      FastLED.show();
      delay(40);
    }        
  }
  else if (fadeVal < currentBright) {
    // fade out
    while (currentBright > fadeVal) {
      currentBright--;
      //for (int i = 0; i < NUM_LEDS; i++) {
      //  leds[i] = CHSV(0, led_color, 255);
      //}
      FastLED.setBrightness(currentBright);
      FastLED.show();
      delay(40);
    }
  }
}

// board setup
void setup() {
  Serial.begin(115200);
  delay(1000);
  Serial.print("Connecting to ");
  Serial.println(ssid);
   
  pinMode(LED_BUILTIN, OUTPUT); 

  //ESPclient.allowSelfSignedCerts();
  //ESPclient.setTrustAnchors(&cert);
  //ESPclient.setInsecure();
  //ESPclient.setCACert(ca_root);
  //ESPclient.setFingerprint(ca_fingerprint);
  
  WiFi.mode(WIFI_STA);
  WiFi.begin(ssid, passwd);

  client.setServer(mqtt_server, mqtt_port);
  client.connect(mqtt_clientID, mqtt_user, mqtt_passwd);
  //client.setCallback(receivedCallback);

  // Mic setup
  // Create FreeRTOS queue
  samples_queue = xQueueCreate(8, sizeof(sum_queue_t));
  
  // Create the I2S reader FreeRTOS task
  xTaskCreate(mic_i2s_reader_task, "Mic I2S Reader", I2S_TASK_STACK, NULL, I2S_TASK_PRI, NULL);

  // LED strip
  FastLED.addLeds<LED_TYPE,DATA_PIN,COLOR_ORDER>(leds, NUM_LEDS).setCorrection(TypicalLEDStrip);

  // set initial color + brightness
  for (int i = 0; i < NUM_LEDS; i++) { 
    leds[i] = CRGB::White;
  }
  FastLED.setBrightness(BRIGHTNESS);
  FastLED.show();
  delay(20);
}

void loop() {
  if (WiFi.status() != WL_CONNECTED) {
    digitalWrite(LED_BUILTIN, HIGH);
    WiFi_connect();
    delay(2000);
  }
  if (!client.connected()) {
    mqtt_connect();
  }
  client.loop();
  // 
  // mic capture
  //
  sum_queue_t q;
  uint32_t Leq_samples = 0;
  double Leq_sum_sqr = 0;
  double Leq_dB = 0;
  
  // Read sum of samples, calculated by 'i2s_reader_task'
  while (xQueueReceive(samples_queue, &q, portMAX_DELAY)) {
    double short_RMS = sqrt(double(q.sum_sqr_SPL) / SAMPLES_SHORT);
    double short_SPL_dB = MIC_OFFSET_DB + MIC_REF_DB + 20 * log10(short_RMS / MIC_REF_AMPL);
    
    // In case of acoustic overload or below noise floor measurement, report infinty Leq value
    if (short_SPL_dB > MIC_OVERLOAD_DB) {
      Leq_sum_sqr = INFINITY;
    } else if (isnan(short_SPL_dB) || (short_SPL_dB < MIC_NOISE_DB)) {
      Leq_sum_sqr = -INFINITY;
    }

    // Accumulate Leq sum
    Leq_sum_sqr += q.sum_sqr_weighted;
    Leq_samples += SAMPLES_SHORT;

    // When we gather enough samples, calculate new Leq value
    if (Leq_samples >= SAMPLE_RATE * LEQ_PERIOD) {
      double Leq_RMS = sqrt(Leq_sum_sqr / Leq_samples);
      Leq_dB = MIC_OFFSET_DB + MIC_REF_DB + 20 * log10(Leq_RMS / MIC_REF_AMPL);
      Leq_sum_sqr = 0;
      Leq_samples = 0;
      
      // dB(A) output
      Serial.printf("%.1f\n", Leq_dB);
      break;
    }
  }
  //
  // LED brightness:
  // 1%: 35-39 dB(A)
  // ...
  // 100%: 100 - 135 dB(A)
  //
  // TODO: confirm scale
  //
  switch (int(Leq_dB)) {
    case 35 ... 39:
      LED_fade(0, 5, currentBright);
      currentBright = 5;
      Serial.println("level: 2%");
      break;
    case 40 ... 49:
      LED_fade(16, 20, currentBright);
      currentBright = 20;
      Serial.println("level: 5%");
      break;
    case 50 ... 59:
      LED_fade(32, 40, currentBright);
      currentBright = 40;
      Serial.println("level: 15%");
      break;
    case 60 ... 69:
      LED_fade(64, 89, currentBright);
      currentBright = 89;
      Serial.println("level: 35%");
      break;
    case 70 ... 79:
      LED_fade(96, 115, currentBright);
      currentBright = 115;
      Serial.println("level: 45%");
      break;
    case 80 ... 89:
      LED_fade(128, 166, currentBright);
      currentBright = 166;
      Serial.println("level: 65%");
      break;
    case 90 ... 99:
      LED_fade(200, 217, currentBright);
      currentBright = 217;
      Serial.println("level: 85%");
      break;
    case 100 ... 135:
      LED_fade(255, 255, currentBright);
      currentBright = 255;
      Serial.println("level: max");
      break;
    default:
      Serial.println("level: out of range");
      break;
  }
  // polling every 60s
  now = millis();
  if (now - last_msg > 60000) {
    last_msg = now;
    // SENSOR1
    dtostrf(Leq_dB, 5, 1, tempString);
    client.publish(SENSOR1_TOPIC, tempString);
    Serial.println("Sensor topic: ");
    Serial.println(tempString);
  }
}

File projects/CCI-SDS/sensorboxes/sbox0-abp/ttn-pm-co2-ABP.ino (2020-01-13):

 /* 
  *  SDS sensorbox prototype, v.0.2
  *  
  *  DEV_NAME=mendes
  *  DEV_ID=sbox0
  *  LOC=loc0
  *  
  *  Sensor list:
  *  SENSOR1 = PMS7003 (pm2.5, pm10)
  *  SENSOR2 = Sensiron SCD30 (CO2, temp, humidity)
  *  
  *  Depends on:
  *  Arduino-lmic, RTCZero, PMS, Sparkfun SCD30 library
  *  
  *  LoRA activation method: 
  *  ABP
  * 
  *  Derives from:
  *  Copyright (c) 2015 Thomas Telkamp and Matthijs Kooijman
  *  Copyright (c) 2018 Terry Moore, MCCI
  *  Copyright (c) 2018 Brent Rubell, Adafruit Industries
  *  
  */

#include <lmic.h> 
#include <hal/hal.h>
#include <SPI.h>
#include <Wire.h>
#include <PMS.h>
#include <RTCZero.h>
#include <SparkFun_SCD30_Arduino_Library.h>
#include "ttn-credentials.h"

// init sensor objs
PMS pms(Serial1);
PMS::DATA data;
SCD30 CO2Sensor;

// RTC init settings
RTCZero rtc;

const uint8_t seconds = 0;
const uint8_t minutes = 0;
const uint8_t hours = 0;

const uint8_t day = 1;
const uint8_t month = 1;
const uint8_t year = 69;

// TTN credentials are located in 'ttn-credentials.h'
// DISABLE_JOIN must be set in 'arduino-lmic/project_config/lmic_project_config.h'
void os_getArtEui (u1_t* buf) { }
void os_getDevEui (u1_t* buf) { }
void os_getDevKey (u1_t* buf) { }

// payload to TTN gateway
static uint8_t payload[14];
static osjob_t sendjob;

// sleep interval in X minutes
const unsigned SLEEP_INTERVAL = 15;

// pin mapping for Feather M0
const lmic_pinmap lmic_pins = {
    .nss = 8,
    .rxtx = LMIC_UNUSED_PIN,
    .rst = 4,
    .dio = {3, 6, LMIC_UNUSED_PIN}, // jumper pin 6 -> IO1 
    .rxtx_rx_active = 0,
    .rssi_cal = 8, // LBT cal for the Feather M0, in dB
    .spi_freq = 8000000,
};

// pin mapping for RST function of PMS7003
const int pmsRSTpin = 5;

// RTC drift for every alarm event 
void alarmMatch() {
    int alarmMinutes = rtc.getMinutes();
    alarmMinutes += SLEEP_INTERVAL;
    if (alarmMinutes >= 60){
        alarmMinutes -= 60;
    }
    rtc.setAlarmMinutes(alarmMinutes);
    rtc.enableAlarm(rtc.MATCH_MMSS);
}

// LoRa event handling
void onEvent (ev_t ev) {
    Serial.print(os_getTime());
    Serial.print(": ");
    switch(ev) {
        case EV_SCAN_TIMEOUT:
            Serial.println(F("EV_SCAN_TIMEOUT"));
            break;
        case EV_BEACON_FOUND:
            Serial.println(F("EV_BEACON_FOUND"));
            break;
        case EV_BEACON_MISSED:
            Serial.println(F("EV_BEACON_MISSED"));
            break;
        case EV_BEACON_TRACKED:
            Serial.println(F("EV_BEACON_TRACKED"));
            break;
        case EV_JOINING:
            Serial.println(F("EV_JOINING"));
            break;
        case EV_JOINED:
            Serial.println(F("EV_JOINED"));
            {
              u4_t netid = 0;
              devaddr_t devaddr = 0;
              u1_t nwkKey[16];
              u1_t artKey[16];
              LMIC_getSessionKeys(&netid, &devaddr, nwkKey, artKey);
              Serial.print("netid: ");
              Serial.println(netid, DEC);
              Serial.print("devaddr: ");
              Serial.println(devaddr, HEX);
              Serial.print("artKey: ");
              for (size_t i=0; i<sizeof(artKey); ++i) {
                if (i != 0)
                  Serial.print("-");
                  Serial.print(artKey[i], HEX);
              }
              Serial.println("");
              Serial.print("nwkKey: ");
              for (size_t i=0; i<sizeof(nwkKey); ++i) {
                 if (i != 0)
                   Serial.print("-");
                   Serial.print(nwkKey[i], HEX);
              }
              Serial.println("");
            }
            // Disable link check validation (automatically enabled
            // during join, but because slow data rates change max TX
            // size, we don't use it in this example.
            LMIC_setLinkCheckMode(0);
            break;
        
        case EV_JOIN_FAILED:
            Serial.println(F("EV_JOIN_FAILED"));
            break;
        case EV_REJOIN_FAILED:
            Serial.println(F("EV_REJOIN_FAILED"));
            break;
            break;
        case EV_TXCOMPLETE:
            Serial.println(F("EV_TXCOMPLETE (includes waiting for RX windows)"));
            if (LMIC.txrxFlags & TXRX_ACK)
              Serial.println(F("Received ack"));
            if (LMIC.dataLen) {
              Serial.println(F("Received "));
              Serial.println(LMIC.dataLen);
              Serial.println(F(" bytes of payload"));
            }
            // Standby mode
            Serial.println(":: now in standby ::");
            digitalWrite(LED_BUILTIN, LOW);
            // rtc.standbyMode();
            // and detach USB
            USB->DEVICE.CTRLA.reg &= ~USB_CTRLA_ENABLE;
             __WFI();
            // Return from Standby
            // and re-attach USB
            USB->DEVICE.CTRLA.reg |= USB_CTRLA_ENABLE;
            Serial.println("");
            Serial.println(":: waking up from standby ::");
            digitalWrite(LED_BUILTIN, HIGH);
            // Schedule next transmission
            do_send(&sendjob);
            break;
        case EV_LOST_TSYNC:
            Serial.println(F("EV_LOST_TSYNC"));
            break;
        case EV_RESET:
            Serial.println(F("EV_RESET"));
            break;
        case EV_RXCOMPLETE:
            // data received in ping slot
            Serial.println(F("EV_RXCOMPLETE"));
            break;
        case EV_LINK_DEAD:
            Serial.println(F("EV_LINK_DEAD"));
            break;
        case EV_LINK_ALIVE:
            Serial.println(F("EV_LINK_ALIVE"));
            break;
        case EV_TXSTART:
            Serial.println(F("EV_TXSTART"));
            break;
        default:
            Serial.print(F("Unknown event: "));
            Serial.println((unsigned) ev);
            break;
    }
}
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

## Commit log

2019-09-22 added sensors libraries.
2019-11-14 adding PMS7003 connector design files.
    [pms7003-conn-B.Cu.gbr, pms7003-conn-B.Mask.gbr, pms7003-conn-B.Paste.gbr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]
2019-12-04 major clean-up + PMS low-power fixes by jimster.
    [ttn-pm-co2.ino]
2019-12-05 minor: improved CO2 sensor responsivity, plus header file w/ TTN credentials.
2020-01-14 Toggleable debug mode (#6)
    * made the debug a #define which is toggleable to disable the serial terminal
    * disabled serial terminal. minor fix
    [ttn-pm-co2.ino]
2020-01-18 minor: changed response time for SCD30, tx power for LoRa.
2020-02-15 WIP schematic.
    [bat_pol_prot.sch, load.sch, pwr_mgr.sch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]
2020-02-15 added symbols for buck converter & boost converter + preliminary schematic for the overall system architecture.
    [load.sch, wsn.sch]
2020-02-17 Rev2 (#8)
    * WIP schematic.
    [bat_pol_prot.sch, load.sch, pwr_mgr.sch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]
2020-02-18 developed more of the schematic for the STM32 + radio. also picked out passives & figured out bidirectional battery polarity checking + reverse polarity protection for the solar panel.
    [bat_pol_prot.sch, load.sch, mcu.sch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]
2020-02-19 exposing pins for mcu, added part values for RF section
    [load.sch, mcu.sch, pmu_config.sch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]
2020-02-19 added a schematic pdf folder
2020-02-19 some preliminary power figure estimation
    [load.sch, pwr_mgr.sch, wsn.sch]
2020-02-19 dont know if i committed everything
    [wsn.sch]
2020-03-02 adding new test board: smoke detector w/ ATTINY85 + LCD 16x2.
2020-03-03 major re-organization of directories and files.
    [pms7003-conn-B.Cu.gbr, pms7003-conn-B.Mask.gbr, pms7003-conn-B.Paste.gbr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]
2020-03-04 adding README for CCI+SDS project.
    [pms7003-conn-B.Cu.gbr, pms7003-conn-B.Mask.gbr, pms7003-conn-B.Paste.gbr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]
2020-03-04 major clean-up, minor updated of README.
    [pms7003-conn-B.Cu.gbr, pms7003-conn-B.Mask.gbr, pms7003-conn-B.Paste.gbr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]
2020-03-05 Created testing platform for SCD30, SGP30, and BME680 sensors (#12)
    * initial commit establishing the file structure for the sensor box test bench. libraries have not been updated yet and modifications have yet to be added for the true build.
    * rewrote the driving .ino sketch to source eCO2 from the SGP30 sensor, actual CO2 from the SCD30 sensor after initializing
    * added BME680 reading functions to the setup. end result = comparing BME680, SCD30, SGP30
    * fixed a massive bug with the bme sensor read. was exiting out of loop() upon a failed read.
    * posterity commit with a clean 'private settings' file and all of the code in place
    [sensorbox-co2-tester.ino]
2020-03-08 adding SAML21 dev board documentation.
    [SAMC21E15A.cfg, SAMC21E16A.cfg, SAMC21E17A.cfg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]
2020-03-24 Added 3D support files
    [Support_PMS7003.stl, Support_Sensirion_SCD30.stl]
2020-04-24 added 3D design files for insulated box.
    [Sensenet_Internal_@B.stl, Sensenet_Side_@B.stl, Sensenet_Side_@B_text.stl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]
2020-04-24 minor: removed left-over STL files.
    [Support_PMS7003.stl, Support_Sensirion_SCD30.stl]
2020-09-01 merge board design files (#16)
    * added some GPS parsing code, set up to acquire a fix at boot, then put the GPS into low power mode;
    * added a crystal for board design. subbed in RFM95, added external pullups for i2C.
    * added a hierarchical sheet for the core and chose abstracted labels for the pins. reorganized sheet
    * added board layout, changed antenna connector
    [bat_pol_prot.sch, board.kicad_pcb, board.sch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]
2020-09-01 minor: updated README, reorganized project files.
    [board.kicad_pcb, board.sch, board_bom_.csv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]
2020-09-07 fixed missing symbols, 3D models; started routing.
    [board.kicad_pcb, board.sch, core.sch]
2020-09-08 added src code for Ostenda installation w/ ESP32S.
2020-09-28 New PCB Layout (#27)
    * Began new PCB layout
    * Updated .gitignore
    * Revised board according to feedback, added silkscreen details
    * Fixed silkscreening at top right
    * updated AUTHORS file
    * minor: adjusted trace, USB / JST alignment, L1 footprint
    * changed cap values for XTAL (HC49S)
    * added +3v3, GND pins on J4 and J5
    * generated and checked Gerber files
    [board-B_Cu.gbl, board-B_Mask.gbs, board-B_Paste.gbp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]
2020-09-29 minor: added M2 mouting holes and re-generated Gerber files.
    [board-B_Cu.gbl, board-B_Mask.gbs, board-B_Paste.gbp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]
2020-09-30 revised BOM, added datasheets and part numbers.
    [board_bom_.csv]
2020-10-19 wIP: added temporary files for build bootloader for XPLAINED board, SAML21J18B.
    [SAMC21J15A.cfg, SAMC21J16A.cfg, SAMC21J17A.cfg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]
2020-11-11 PCB Revision 2 (#29)
    * Work on rev 2
    * Routed missing VBUS net
    * Optimized track routing
    * Cleared DRC errors
    * Replaced part U1, improved board
    * Added digital I/O labels to silkscreen
    * removed R7 (duplicate);
    * fixed track sizes
    * adjusted values + labels on schematic and board for Q1, Q2, and R4.
    [board-B_Cu.gbl, board-B_Mask.gbs, board-B_Paste.gbp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]

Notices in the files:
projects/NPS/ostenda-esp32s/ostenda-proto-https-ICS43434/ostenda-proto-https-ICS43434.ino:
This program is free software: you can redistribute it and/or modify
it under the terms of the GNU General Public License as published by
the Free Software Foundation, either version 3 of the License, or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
